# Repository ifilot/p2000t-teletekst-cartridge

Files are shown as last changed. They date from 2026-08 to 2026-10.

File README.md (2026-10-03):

# P2000T Teletekst Cartridge





<p align="center">
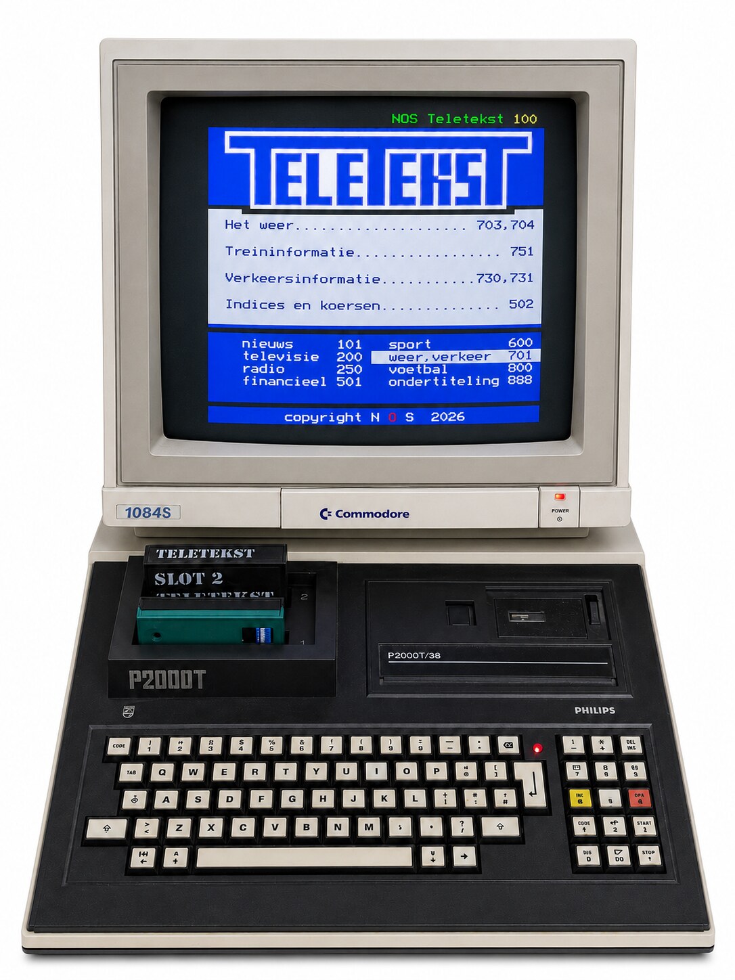
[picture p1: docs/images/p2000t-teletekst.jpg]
Philips P2000T displaying NOS Teletekst through the cartridge
  
</p>

## Introduction

The P2000T Teletekst Cartridge brings internet-connected teletext to the Philips
P2000T. A slot-1 ROM provides the native SAA5050 user interface, while a
Raspberry Pi Pico W or Pico 2 W interface in slot 2 manages Wi-Fi and fetches
pages from the NOS service, the P2000T community service,
[TeletekstArchief.nl](https://teletekstarchief.nl), or a user-supplied HTTP(S)
server. Together, they provide wireless network setup, optional
encrypted credential storage, and direct three-digit page selection on the
original computer.

This repository contains the public hardware and client side of the P2000T
Teletekst project:

- `src/` is the 16 KiB slot-1 cartridge client.
- `firmware/` is the Raspberry Pi Pico W firmware for the slot-2 interface.
- [`docs/protocol.md`](docs/protocol.md) defines the P2WP/2–8 link protocol
  between them.
- [`docs/custom-server.md`](docs/custom-server.md) gives the small HTTP/JSON
  contract needed to host your own pages.
- [`server/`](server/) contains a dependency-free Python example server and
  editable test page.
- `pcb/` contains the KiCad hardware design and manufacturing files.
- `enclosure/` contains the enclosure and label models.

## Downloads

Download the latest release artifacts:

- [P2000T cartridge ROM (`p2wp-cartridge.bin`)](https://github.com/ifilot/p2000t-teletekst-cartridge/releases/latest/download/p2wp-cartridge.bin)
- [Raspberry Pi Pico W firmware (`p2wp-pico-w.uf2`)](https://github.com/ifilot/p2000t-teletekst-cartridge/releases/latest/download/p2wp-pico-w.uf2)
- [Raspberry Pi Pico 2 W firmware (`p2wp-pico-2-w.uf2`)](https://github.com/ifilot/p2000t-teletekst-cartridge/releases/latest/download/p2wp-pico-2-w.uf2)

## Installing the firmware

Download all required binaries from the [Downloads](#downloads) section. Turn
the P2000T off before inserting or removing either cartridge.

### Slot-1 cartridge ROM

`p2wp-cartridge.bin` is a raw, signed 16 KiB ROM image for the slot-1
Teletekst cartridge. The programming procedure depends on the ROM, EEPROM, or
flash cartridge being used:

1. Select the exact memory device fitted to the cartridge in its programmer or
   flashing software.
2. Load `p2wp-cartridge.bin` as a raw binary. Do not byte-swap or add a file
   header.
3. Erase the device first if its technology requires it, then program and
   verify all 16,384 bytes.
4. Disconnect the programmer and insert the cartridge into slot 1 while the
   P2000T is powered off.

If the cartridge has an integrated loader rather than a removable memory chip,
follow that cartridge's instructions and use `p2wp-cartridge.bin` as its ROM
image. Do not guess a memory-device setting: an incorrect programming voltage
or pin configuration can damage the device.

### Pico W or Pico 2 W

> [!IMPORTANT]
> The Pico W and Pico 2 W use different firmware images, and the module marking
> may be hidden inside the cartridge. When the BOOTSEL drive opens in File
> Explorer, identify the Pico by its drive name: `RPI-RP2` means Pico W and
> `RP2350` means Pico 2 W. Do not copy a firmware file until the drive name has
> been checked.

| Installed module | BOOTSEL drive | Firmware file |
| --- | --- | --- |
| Raspberry Pi **Pico W** (RP2040) | `RPI-RP2` | `p2wp-pico-w.uf2` |
| Raspberry Pi **Pico 2 W** (RP2350) | `RP2350` | `p2wp-pico-2-w.uf2` |

1. Turn off the P2000T. Leave it off throughout the update.
2. Connect a data-capable USB cable to the Pico while holding its **BOOTSEL**
   button, then release the button when the USB drive appears.
3. In File Explorer (or the equivalent file manager), check the BOOTSEL drive
   name against the table above to determine which Pico variant is installed.
4. Copy the matching `.uf2` file to that drive. The drive automatically ejects
   and the Pico reboots when programming is complete.
5. Unplug the USB cable, install the slot-2 cartridge if it was removed, and
   then power on the P2000T.

BOOTSEL is stored in the Pico's read-only boot ROM, so this update method
remains available even if an earlier firmware image does not start. See the
official [Raspberry Pi drag-and-drop instructions](https://www.raspberrypi.com/documentation/microcontrollers/c_sdk.html#your-first-binaries)
for more detail.

#### Pico W versus Pico 2 W performance

Both modules provide the same cartridge features and should feel the same in
normal use. Page loading is dominated by the shared CYW43439 wireless subsystem,
Internet and server latency, and the same negotiated P2WP cartridge transport, so the
Pico 2 W's faster processor is not expected to provide a noticeable benefit
here.

## Hardware

<p align="center">
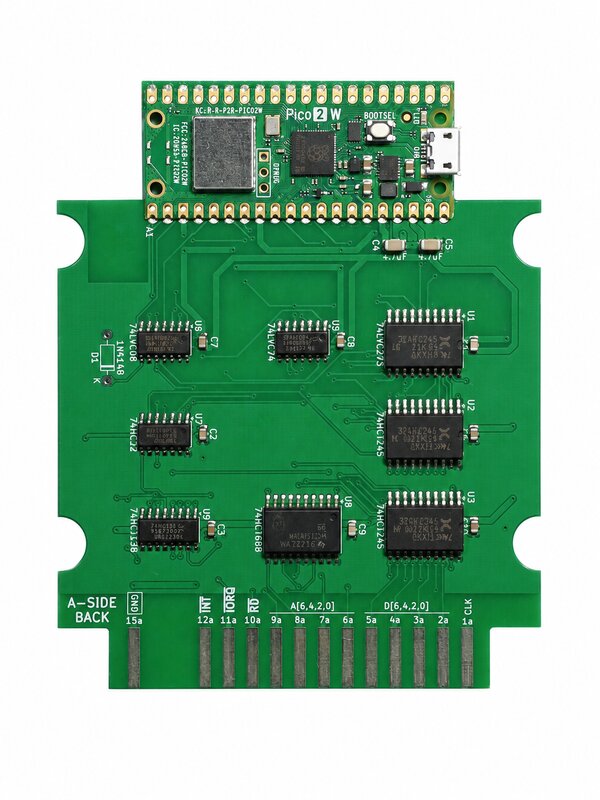
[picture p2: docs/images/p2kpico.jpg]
P2000T Teletekst cartridge with Raspberry Pi Pico 2 W
  
</p>

### Enclosure

<p align="center">
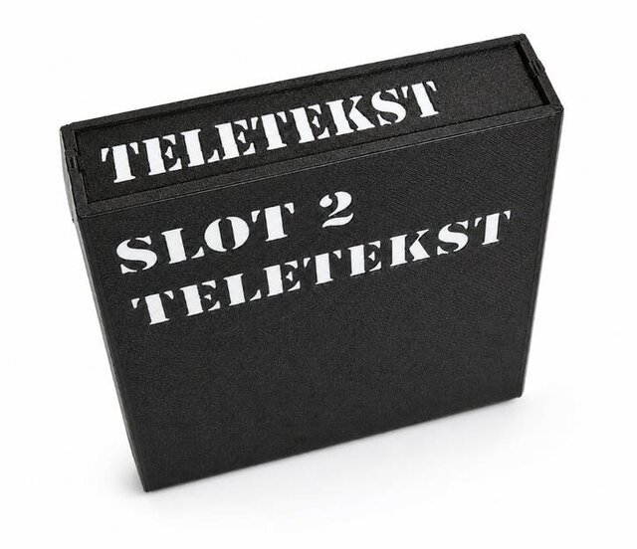
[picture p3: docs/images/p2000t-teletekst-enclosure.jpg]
Completed P2000T Teletekst cartridge enclosure
  
</p>

The printable enclosure and label models are available in [`enclosure/`](enclosure/).

### Circuit schematic

<p align="center">
  <a href="pcb/p2000t-pico-web-interface.svg">
    P2000T Teletekst cartridge circuit schematic
  </a>
</p>

## Documentation

The source menu offers NOS, P2000T Teletekst, TeletekstArchief.nl, international channels through PetsciiProxy, and a custom
server. Press `A` on that menu to choose which source should start after the
opening screen has been left untouched for 60 seconds; cycle to `UIT` to disable
auto-start. The opening prompt shows the remaining `AUTO-MODE` seconds beside
`DRUK OP EEN TOETS`. An automatic start also enables automatic next-page mode.

Choose **1 - NOS TELETEKST** for `https://teletekst-data.nos.nl`. For example,
page 101 is available at `https://teletekst-data.nos.nl/json/101-0`; the NOS
source already uses this service, so no custom server URL is needed.

Choose **4 - PETSCIIPROXY.NL** for the channels at
[`http://petsciiproxy.nl:8080`](http://petsciiproxy.nl:8080). Use `P`/`N` or the
arrow keys to browse four lists, `1`–`9` to select a channel, and `STOP` to
return. The 35 presets include ARD, ZDF, ORF, Ceefax, Teefax, Nordic and Swiss
services, and community channels. This requires updated Pico firmware supporting
P2WP/8. Channel selection lasts for the session; the saved custom URL and
autostart choice are preserved. Availability depends on the upstream service;
MTVA is omitted because upstream lists it as offline. Accented letters use
Viewdata fallbacks where the P2000T character set cannot display them.
The cartridge date/time overlay is disabled for these channels so their own
header clock remains visible. This default is configured in the cartridge ROM.

### Keymap

The on-screen help uses the P2000T's native `←` and `→` display glyphs for the
physical arrow keys. Those arrows and `P`/`N` select pages. The literal `<` and
`>` keys select the previous and next subpage; `S` selects one directly and `A`
pauses or resumes automatic rotation. `L` also toggles this subpage looping.
While paused, automatic page navigation also waits, keeping the displayed
page and subpage fixed until you resume.

| Context | Key | Action |
| --- | --- | --- |
| Page | `100`–`899` | Type three digits to fetch a page; Backspace edits an unfinished number |
| Page | `START` or `I` | Go to index page 100 |
| Page | `←` or `P`; `→` or `N` | Follow the server's previous/next-page link |
| Page | `<`; `>` | Fetch the numerically previous/advertised next subpage |
| Page | `S` | Select a subpage (`00` asks for the default subpage) |
| Page | `L` / `A` | Toggle automatic subpage looping (pause/resume) |
| Page | `V` | Toggle automatic next-page mode |
| Page | `?` or `R` | Reveal or conceal hidden text |
| Page | `Z` | Cycle normal, upper-half, and lower-half zoom |
| Page | `H` | Open the on-screen help page; any key returns |
| Page | `W` | Return to Wi-Fi setup |
| Page | `STOP` | Return to source selection |
| Source menu | `1`, `2`, `3`, `4`, or `0` | Choose NOS, P2000T, Archive, international channels, or a custom server |
| Source menu | `A` | Cycle the persistent 60-second auto-start source |
| Source menu | `H` | Open the on-screen help page |
| Input dialog | Backspace | Delete the last character or digit |
| Input dialog | Shift-`STOP` | Cancel Wi-Fi or custom-server input |

The main number row and numeric keypad both work for page and subpage entry.

Choose **0 - EIGEN SERVER** to enter an `http://` or `https://` URL of up to 96
characters, including an optional port and base path. The address is retained
in Pico flash and is filled in the next time this dialog opens. Flash is only
updated when the address changes. See [Hosting a custom Teletekst
server](docs/custom-server.md) for the required routes and response fields.

> [!WARNING]
> Certificate and hostname verification is disabled for a custom HTTPS server,
> so self-signed and private-CA certificates work. Use only a server and network
> you trust. The built-in services continue to use verified HTTPS. Archive
> requires P2WP/7 so it always uses the dedicated, verified transport.

[`docs/protocol.md`](docs/protocol.md) is the canonical P2WP/2–8 interface
specification. The Sphinx documentation also includes a
[P2000T BASIC](docs/basic.rst) client guide.

Pushes to `master` publish the rendered documentation to
[GitHub Pages](https://ifilot.github.io/p2000t-teletekst-cartridge/). Manual
deployment is also available from the GitHub Actions page. Before the first
deployment, select **GitHub Actions** as the publishing source under
**Settings → Pages**.

Build the HTML documentation with:

```sh
python3 -m pip install -r docs/requirements.txt
make -C docs html
```

## Compilation

### Quick start

From the repository root, `make run` builds the emulator and cartridge and
boots it in the emulator. This needs the dependencies listed in
[`emulator/README.md`](emulator/README.md). Append emulator options with
`ARGS`, for example `make run ARGS="--p2wp-version 2"`, or replace the network
mode with `EMUFLAGS`.

### Cartridge

Build the production C cartridge in the pinned Z88DK Docker toolchain and run
its emulator integration test with:

```sh
make -C src
make -C src smoke
```

This produces the sole release image, `build/p2wp-cartridge.bin`. See
[`src/README.md`](src/README.md) for its architecture and memory map.

### PICO Firmware

Build the firmware with `cmake -S firmware -B firmware/build -G Ninja` followed
by `cmake --build firmware/build`; this requires `PICO_SDK_PATH` to point to a
Raspberry Pi Pico SDK.

The host-side replay tool fetches a live NOS response and passes it through the
same size limit and JSON-to-SAA5050 decoder as the Pico firmware:

```sh
firmware/tools/replay-nos-page 101
firmware/tools/replay-nos-page 200-2
```

For a saved response, build with `make -C firmware/tools` and run
`firmware/tools/teletekst-replay PAGE response.json [screen.bin]`. Failures are
reported as the Pico's `06`/`07` code plus the rejected decoder stage or row,
which makes captured API responses suitable as regression fixtures.

After Wi-Fi connects, firmware can securely query the repository's latest
GitHub release. Two rows beneath the post-login source menu show that online
version beside the installed cartridge and firmware versions. Both cartridge
and Pico artifacts use the repository's canonical `VERSION` value. The Pico
generation remains available to hosts through the `DEVICE_INFO` protocol command.

The emulator directly compiles the firmware's portable production command
processor. Its end-to-end cartridge tests therefore cover the same protocol
negotiation, validation, retry/sequence rules, device information, and command
dispatch used on the Pico. Deterministic host adapters replace only GPIO,
CYW43 Wi-Fi, network timing, and flash hardware.

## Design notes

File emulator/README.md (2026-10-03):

# P2000T + Teletekst cartridge emulator

This is a focused graphical P2000T emulator for the SLOT1 ROM and SLOT2 Pico W
interface developed in this repository. It uses the M2000 Z80/P2000T core and
authentic `Default.fnt` SAA5050 glyphs. SDL provides the display and keyboard.

Dependencies: CMake, Ninja, SDL2, libcurl, and a C compiler. On Debian/Ubuntu:

```sh
sudo apt install cmake ninja-build libsdl2-dev libcurl4-openssl-dev
```

Build the cartridge and emulator:

```sh
make -C src
make -C emulator
```

and run it via

```sh
emulator/run
```

From the repository root, `make run` performs both steps and starts the
emulator with the cartridge (`build/p2wp-cartridge.bin`). Extra emulator options
go in `ARGS`, and `EMUFLAGS` replaces the default `--live` network mode:

```sh
make run ARGS="--auto-key Z"
make run EMUFLAGS="--fixture emulator/tests/fixtures/nos-100.json"
```

The emulator presents one open network named `Emulated WiFi`; select it with
`1`, decline profile storage with `N`, then choose NOS with `1`. Choose `2` for
P2000T Teletekst, `3` for TeletekstArchief.nl, `4` for the international
channel picker (P2WP/8), or `0` to type a custom server
URL. Regular host
letter, number, arrow, Enter, Backspace, Shift and keypad-Enter (P2000 STOP)
keys are mapped to the P2000T keyboard matrix. Press `F11` for a warm reset or
`F12` for a cold reset.

Page shortcuts are `START`/`I` (page 100), `?`/`R` (reveal), `Z` (top, bottom, and
normal size), arrow left/`P` and arrow right/`N` (previous/next page), `V`
(automatic next page), `<`/`>` (previous/next subpage), `A` (pause subpages),
`S` (choose subpage), `W` (Wi-Fi),
`H` (help), and P2000 `STOP` (source selection). The host
keypad Enter key maps to `STOP`; `I` is the convenient host equivalent for
`START`.

The pytest integration suite uses a tiny generated monitor shim and a recorded
NOS response, so it is deterministic and does not need proprietary ROMs or
network. Install its Python dependency once, then run it from the repository
root:

```sh
python3 -m pip install -r emulator/tests/requirements.txt
make test
```

Pytest captures the emulator's automatic-key trace on successful runs and
includes it in the failure report when a test fails.

It executes the production cartridge, completes negotiated P2WP HELLO, fictitious Wi-Fi
scan/connect, source selection, live-code JSON decoding, four chunk transfers,
and asserts that built-in and custom page content reached emulated video RAM.
It also exercises keypad entry, Backspace, arrows, Shift-STOP cancellation,
persisted auto-start, stale-label cleanup, P2WP/7 Archive gating, auto-page
error recovery, detailed P2WP/7 errors, the expanded help screen, and zoom mode.

For a deterministic custom-source boot from the repository root, run:

```sh
emulator/build/p2000t-emulator \
  --monitor /path/to/P2000ROM.bin --cartridge build/p2wp-cartridge.bin \
  --font emulator/assets/Default.fnt \
  --fixture emulator/tests/fixtures/nos-100.json \
  --headless --auto --auto-source 0 --custom-server http://terra:8080 \
  --frames 650 --dump-screen /tmp/custom-screen.bin
```

Fixture mode tests URL entry and P2WP/5 without network access. Add
`--flash /path/to/pico-flash.bin` to retain the last custom URL across emulator
runs; the file is rewritten only when the accepted URL changes. Replace the
`--fixture` pair with `--live`, change the custom URL to
`http://127.0.0.1:8080`, and run `python3 server/server.py` in another terminal
to contact the included example server. Add
`--auto-key Z`, `--auto-key RIGHT`, or `--auto-keys KP1,KP0,BACKSPACE,KP0,KP1`
to inject one or more page controls
after loading, which keeps new controls quick to test without a physical
keyboard.

The Pico side is a native simulation built around the production
`firmware/src/firmware_core.c` command processor. Consequently, negotiation,
payload validation, device/version replies, retry caching, sequence-conflict
handling, sensitive-payload erasure, and command dispatch are identical to the
real Pico firmware. The emulator supplies deterministic platform operations for
Wi-Fi, HTTP and storage; it does not simulate the RP2040/RP2350 processor,
CYW43 radio, GPIO electrical timing, or Pico SDK drivers.

Use `--p2wp-version 2` to emulate legacy firmware and exercise the cartridge's
compatibility warning, or `--p2wp-version 1` to exercise the no-common-version
error screen. Without this option the emulator negotiates the current P2WP/7.
The intermediate pre-release clock firmware can be reproduced with
`--p2wp-version 2 --p2wp-status-length 9`.

Stalled fetches reproduce the Pico firmware's 60-second HTTP timeout. Pass
`--stall-fetch` (or `--stall-fetch-after N`) to exercise it. The diagnostic
`--no-firmware-fetch-timeout` switch disables that emulation so cartridge-side
75-second fallback handling can be tested independently.

The vendored M2000 core retains its upstream copyright and is GPL-3.0; see
`LICENSE` and `vendor/m2000/UPSTREAM.md`.

For automatic international channel selection, use `--auto --auto-source 4
--auto-channel 3` (ARD). Channel indices follow the cartridge preset table,
starting at zero. Use `--live` for public PetsciiProxy access, or
`--fixture emulator/tests/fixtures/petscii-100.txt` for offline decoding.

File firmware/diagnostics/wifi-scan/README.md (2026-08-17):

# Standalone Pico W scan diagnostic

This deliberately excludes the P2000 mailbox, lwIP, and multicore code. Wi-Fi
scanning is performed directly by the CYW43 driver and does not require an IP
stack. It uses the repository's configured Pico SDK to initialize the CYW43 in
the Netherlands regulatory domain and perform one scan.

The onboard LED blinks slowly during scanning, remains on after one or more
results, and blinks rapidly after a failure or a zero-result scan. USB CDC
output reports the exact initialization and scan status every two seconds. The
diagnostic waits until a terminal has opened the USB CDC serial port before it
prints its startup messages. It then remains idle until a space character is
received over USB. CYW43 initialization and scanning only start after that
explicit command.

Build from this directory with:

```sh
cmake -S . -B build -G Ninja
cmake --build build
```

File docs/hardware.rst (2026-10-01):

Hardware design
===============

The slot-2 cartridge is a bridge between two systems with different buses and
voltage levels. On one side is the P2000T's 5 V, eight-bit I/O bus. On the
other is the Pico W's 3.3 V GPIO. The cartridge decodes three I/O addresses,
moves one byte in each direction, and provides handshake signals so that a
fast endpoint never outruns a slow one.

This page explains the circuit from functional blocks down to the individual
logic devices. The :doc:`protocol` specifies the software-visible behaviour.

At a glance
-----------

Data and handshake paths between the P2000T and Pico W

   The two byte paths are independent. ``STATUS`` lets the P2000T determine
   when it may write and when a received byte is available.

The P2000T always initiates a protocol transaction, but bytes can travel in
either direction. A one-byte input register protects Pico-bound data; the Pico
holds host-bound data stable until the P2000T reads it. Separate flip-flops
remember the state of each handshake.

Complete schematic
------------------

Complete black-and-white circuit schematic for the P2000T Pico Web Interface

   Complete cartridge circuit. Open the image separately to inspect component
   references, pin numbers, and signal names at full resolution.

The editable design is in the `KiCad schematic`_; a `standalone SVG`_ is also
available. The SVG is generated from that source in black and white.

Address decoding and port strobes
---------------------------------

The P2000T presents address bits, data bits, ``/IORQ``, ``/RD``, ``/WR``, and
``/RES`` on connector **J1**. The cartridge responds only to I/O addresses
``0x40`` through ``0x42``:

.. list-table::
   :header-rows: 1
   :widths: 16 20 24 40

   * - Port
     - Bus operation
     - Internal strobe
     - Selected circuit
   * - ``0x40``
     - Write
     - ``/WRx40``
     - U1 input register and U5A transmit-state flip-flop
   * - ``0x41``
     - Read
     - ``/RDx41``
     - U2 output-bus buffer and U5B receive-acknowledge flip-flop
   * - ``0x42``
     - Read
     - ``/RDx42``
     - U3 status-bus buffer

**U8**, a 74HCT688 equality comparator, recognizes the ``0x4x`` address
range. **U9**, a 74HCT138 decoder, then uses A0 through A2 to select ``0x40``,
``0x41``, or ``0x42``. Gates in **U7** combine those active-low selections
with the P2000T read or write control signal. This produces a strobe only for
the correct port and bus operation.

P2000T-to-Pico data path
-------------------------

#. Software waits until status bit 1, ``TX_READY``, is high.
#. An ``OUT`` to ``0x40`` places D0 through D7 on the P2000T bus and pulses
   ``/WRx40``.
#. **U1**, a 74LVC273 powered at 3.3 V, captures that byte and presents it as
   ``PD0`` through ``PD7`` to Pico GPIO0 through GPIO7.
#. The same write clocks **U5A**. Its outputs assert ``TX_FULL`` and deassert
   ``TX_READY``, recording that U1 contains an unread byte.
#. The Pico samples GPIO0 through GPIO7, then pulses ``/TX_CLR`` low. **U6A**
   combines that signal with reset and clears U5A, making ``TX_READY`` high
   again.

U1 holds the byte independently of the P2000T bus. The host must nevertheless
wait for ``TX_READY`` before every write: a second write would replace the byte
before the Pico had consumed it.

Pico-to-P2000T data path
-------------------------

#. The Pico waits for ``RX_ACK_PENDING`` to be low, then drives GPIO8 through
   GPIO15 (``PD8`` through ``PD15``) and asserts ``RX_READY``.
#. Software observes ``RX_READY`` in status bit 0 and performs an ``IN`` from
   ``0x41``.
#. ``/RDx41`` enables **U2**, a 74HCT245, which drives the Pico byte onto D0
   through D7 for the duration of the read.
#. The end of the read clocks **U5B**, asserting ``RX_ACK_PENDING`` to tell the
   Pico that the byte was accepted.
#. The Pico deasserts ``RX_READY`` and pulses ``/RX_ACK_CLR``. **U6B** then
   clears U5B so another byte can be sent.

There is no second storage register in this direction: the Pico itself keeps
GPIO8 through GPIO15 stable from ``RX_READY`` until the read is acknowledged.
Reading ``0x41`` more than once for the same byte would create an ambiguous
acknowledgement, so the host reads it exactly once.

Status register
---------------

**U3** is another 74HCT245. A read from ``0x42`` enables it and places the
following signals on the P2000T data bus:

.. list-table::
   :header-rows: 1
   :widths: 12 30 58

   * - Bit
     - Signal
     - Source or purpose
   * - 0
     - ``RX_READY``
     - Pico: a host-bound byte is stable
   * - 1
     - ``TX_READY``
     - U5A: U1 can accept another byte
   * - 2
     - ``WIFI_UP``
     - Pico application state
   * - 3
     - ``BUSY``
     - Pico application state
   * - 4
     - ``ERROR``
     - Pico application state
   * - 5
     - ``RX_ACK_PENDING``
     - U5B: the P2000T has read the current byte
   * - 6
     - ``TX_FULL``
     - U5A: U1 contains a Pico-bound byte
   * - 7
     - Ground
     - Reserved; always reads as zero

Only U2 or U3 drives the P2000T data bus, and only during its corresponding
read strobe. At all other times their outputs are high impedance. This avoids
contention with the computer and with other devices on the bus.

Voltage domains, power, and reset
---------------------------------

The cartridge receives 5 V and ground from J1. The 5 V rail powers the Pico
through ``VSYS`` and powers the 74HCT bus-side devices. The Pico's regulated
3.3 V output supplies U1, U5, and U6.

The logic families provide the level boundary. The 3.3 V 74LVC input register
accepts the P2000T's 5 V bus signals and produces 3.3 V GPIO levels. In the
opposite direction, the 5 V 74HCT245 buffers recognize the Pico's 3.3 V output
levels and drive valid 5 V-side bus levels. The control flip-flops and gates
remain in the 3.3 V domain.

**U6C** translates the active-low P2000T reset into ``/RES_3V3`` for the Pico.
Reset also clears the two handshake flip-flops, returning the transport to an
empty, known state. C1 through C3 and C6 through C10 provide local decoupling;
C4 and C5 provide bulk capacitance on the 3.3 V and 5 V rails.

Software-visible guarantees
---------------------------

The circuit deliberately provides only one byte of buffering per direction.
Software and firmware therefore form part of the transport:

* the host must poll ``TX_READY`` before writing and ``RX_READY`` before
  reading;
* the Pico must hold outgoing data stable until it sees
  ``RX_ACK_PENDING``;
* the Pico must acknowledge an incoming byte with ``/TX_CLR``;
* every wait must have a finite timeout; and
* reset discards any byte or frame that was partly transferred.

The :ref:`hardware transport section <hardware-transport>` defines the exact
handshake sequence. The :doc:`basic` guide shows how host software implements
it.

.. _KiCad schematic: https://github.com/ifilot/p2000t-teletekst-cartridge/blob/master/pcb/p2000t-pico-web-interface.kicad_sch
.. _standalone SVG: https://github.com/ifilot/p2000t-teletekst-cartridge/blob/master/pcb/p2000t-pico-web-interface.svg

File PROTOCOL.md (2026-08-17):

# P2000T to Pico W Protocol (P2WP/2)

P2WP/2 is a reliable, framed request/response protocol carried by the three
I/O ports on the P2000T Pico W interface. Multi-byte fields are little-endian.

## Hardware transport

The P2000T is the host and the Pico W is the peripheral.

| Port | P2000T operation | Name | Purpose |
| --- | --- | --- | --- |
| `0x40` | write | `HOST_TX` | Send one byte to the Pico |
| `0x41` | read | `HOST_RX` | Receive one byte from the Pico |
| `0x42` | read | `STATUS` | Read transport and application status |

The status register is defined as follows:

| Bit | Schematic signal | Meaning |
| ---: | --- | --- |
| 0 | `RX_READY` | A Pico-to-host byte is ready |
| 1 | `TX_READY` | The host may write `HOST_TX` |
| 2 | `WIFI_UP` | Informational: the network is available |
| 3 | `BUSY` | Informational: the Pico is processing a request |
| 4 | `ERROR` | Informational: the Pico detected an error |
| 5 | `RX_ACK_PENDING` | Diagnostic: the host read `HOST_RX` |
| 6 | `TX_FULL` | Diagnostic: a host-to-Pico byte is pending |
| 7 | reserved | Reads zero |

`TX_READY` and `TX_FULL` are complementary. Only `RX_READY` and `TX_READY`
are used by the P2000T transport implementation; the remaining bits are
advisory or diagnostic.

### Host to Pico byte transfer

1. The host waits until `TX_READY` is one.
2. The host writes exactly one byte to `HOST_TX`.
3. The hardware sets `TX_FULL` and clears `TX_READY`.
4. The Pico samples GPIO0 through GPIO7.
5. The Pico drives `TX_CLR` low until `TX_FULL` clears, then releases it high.

The host must never write while `TX_READY` is zero, because doing so overwrites
the byte latch.

### Pico to host byte transfer

1. The Pico waits until `RX_ACK_PENDING` is zero.
2. The Pico drives the byte on GPIO8 through GPIO15.
3. The Pico sets `RX_READY` high.
4. The host waits for `RX_READY`, then reads `HOST_RX` exactly once.
5. The hardware sets `RX_ACK_PENDING`.
6. The Pico first clears `RX_READY`, then drives `RX_ACK_CLR` low until
   `RX_ACK_PENDING` clears, and finally releases `RX_ACK_CLR` high.

Both endpoints must use a finite timeout for every wait. A transport timeout
aborts the partial frame and causes transaction recovery.

## Framing

`0x7E` is the frame delimiter. A frame consists of a delimiter, an escaped
body, and a closing delimiter. A closing delimiter may also serve as the
opening delimiter for the next frame. Repeated delimiters are idle fill.

Within the body, bytes `0x7E` and `0x7D` are encoded as `0x7D` followed by the
original byte XOR `0x20`. No other bytes are escaped.

The unescaped body is:

| Offset | Size | Field |
| ---: | ---: | --- |
| 0 | 1 | Protocol version (`0x02`) |
| 1 | 1 | Flags |
| 2 | 1 | Message type |
| 3 | 1 | Sequence number |
| 4 | 2 | Payload length |
| 6 | N | Payload |
| 6+N | 2 | CRC-16, low byte first |

The initial maximum payload is 512 bytes. Implementations may advertise a
smaller limit during `HELLO`, but must reject a frame rather than truncate it.

### Flags

| Bit | Name | Meaning |
| ---: | --- | --- |
| 0 | `RESPONSE` | Frame is a response |
| 1 | `ERROR` | Response payload starts with an error code |
| 2 | `MORE` | Additional chunks belong to this transaction |
| 3-7 | reserved | Must be sent as zero and ignored on receipt |

### CRC

The CRC covers the unescaped bytes from version through the final payload
byte. It does not cover delimiters, escape bytes, or the transmitted CRC.

P2WP/2 uses CRC-16/CCITT-FALSE:

- polynomial: `0x1021`
- initial value: `0xFFFF`
- input and output are not reflected
- final XOR: `0x0000`

A receiver silently discards malformed, oversized, truncated, or CRC-invalid
frames. It may set its local error indication and statistics counter.

## Transactions and recovery

The P2000T is the only request initiator in P2WP/2. The Pico sends a frame only
in response to a valid request. This avoids unsolicited traffic and lets future
web events be retrieved with polling requests.

- A new request uses the next sequence number modulo 256.
- A response uses the request's type and sequence number and sets `RESPONSE`.
- An empty successful response is the acknowledgement for a command with no
  result data.
- On timeout, the host retries the identical request with the identical
  sequence number. Three attempts are recommended.
- The Pico caches the most recent request identity and complete response. An
  identical retry resends that response without repeating side effects.
- Reuse of the most recent sequence number for different request content is a
  protocol error.
- After all retries fail, the host abandons the partial frame and starts again
  with `HELLO`.
- A valid non-duplicate `HELLO` starts a session and invalidates older cached
  transaction state.

An inter-byte timeout resets only the frame parser. Transaction timeouts are
message-specific; the MWE uses a short local-link timeout, while future network
operations may use longer timeouts or chunked progress responses.

## Version 2 messages

| Type | Name | Request payload | Successful response payload |
| ---: | --- | --- | --- |
| `0x01` | `HELLO` | Hello request below | Hello response below |
| `0x02` | `ECHO` | Arbitrary bytes | Identical bytes |
| `0x03` | `LINK_STATS` | Empty | Implementation counters; format reserved |
| `0x10` | `WIFI_SCAN_START` | Empty | Empty acknowledgement |
| `0x11` | `WIFI_SCAN_STATUS` | Empty | Scan state, result count, and radio state |
| `0x12` | `WIFI_SCAN_RESULT` | One-byte result index | Indexed network record |
| `0x13` | `WIFI_CONNECT` | Network index and password | Empty acknowledgement |
| `0x14` | `WIFI_STATUS` | Empty | Connection state |
| `0x20` | `WIFI_PROFILE_STATUS` | Empty | Profile state and error |
| `0x21` | `WIFI_PROFILE_CONNECT` | Empty | Empty acknowledgement |
| `0x22` | `WIFI_PROFILE_SAVE` | Wi-Fi password | Empty acknowledgement |
| `0x23` | `WIFI_PROFILE_DELETE` | Empty | Empty acknowledgement |
| `0x30` | `TELETEKST_FETCH_START` | Page, subpage, and source | Empty acknowledgement |
| `0x31` | `TELETEKST_FETCH_STATUS` | Empty | Fetch state, error, byte count, and next subpage |
| `0x32` | `TELETEKST_FETCH_ROWS` | Chunk index | Six display-ready rows |

The eight-byte `HELLO` request is:

| Offset | Field |
| ---: | --- |
| 0-3 | ASCII `P2WP` |
| 4 | Minimum supported version |
| 5 | Maximum supported version |
| 6-7 | Host maximum payload |

The eight-byte `HELLO` response is:

| Offset | Field |
| ---: | --- |
| 0-3 | ASCII `P2WP` |
| 4 | Selected version |
| 5 | Capability bits (`bit 0`: `ECHO`, `bit 1`: Wi-Fi provisioning, `bit 2`: Internet fetch, `bit 3`: encrypted Wi-Fi profile) |
| 6-7 | Negotiated maximum payload |

`HELLO` is independent of Wi-Fi state and must work while `WIFI_UP` is zero.

If the `ERROR` flag is set, the first payload byte is one of:

| Code | Meaning |
| ---: | --- |
| `0x01` | Unsupported version |
| `0x02` | Unknown message type |
| `0x03` | Invalid payload |
| `0x04` | Sequence conflict |
| `0x05` | Internal error |
| `0x06` | Wi-Fi hardware or driver unavailable |
| `0x07` | Wi-Fi operation already in progress |

## Wi-Fi provisioning

Scanning and connecting are asynchronous so the Pico can acknowledge every
link transaction quickly. The host starts an operation and polls its status;
it must not hold a P2WP transaction open for the duration of a radio scan,
authentication exchange, or DHCP request.

`WIFI_SCAN_STATUS` returns three bytes:

| Offset | Field |
| ---: | --- |
| 0 | State: `0` idle, `1` scanning, `2` complete, `3` failed |
| 1 | Number of results reported so far (final when complete) |
| 2 | Radio state: `0` initializing, `1` ready, `2` initialization failed |

Radio initialization and scanning have finite implementation deadlines. A
queued scan may report state `1` with radio state `0` while CYW43 startup is
still in progress; it changes to scan state `3` if startup or scanning exceeds
its deadline.

Results are de-duplicated by SSID, retaining the strongest access point, and
ordered by decreasing RSSI. A `WIFI_SCAN_RESULT` response is:

| Offset | Field |
| ---: | --- |
| 0 | Result index from the request |
| 1 | RSSI in dBm as a signed 8-bit integer |
| 2 | Security: `0` open, `1` supported WPA/WPA2 PSK, `2` unsupported |
| 3 | SSID length, 1-32 |
| 4 | SSID bytes, not zero-terminated |

A `WIFI_CONNECT` request contains:

| Offset | Field |
| ---: | --- |
| 0 | Index from the most recently completed scan |
| 1 | Password length, 0-63 |
| 2 | Password bytes, not zero-terminated |

The password must be empty for an open network and 8-63 bytes for a secured
network. `WIFI_STATUS` returns one state byte: `0` disconnected, `1`
connecting, `2` connected with an IP address, `3` SSID not found, `4`
authentication failed, or `5` connection failed/timed out.

## Encrypted Wi-Fi profile

The Pico may store one optional Wi-Fi profile. Profile operations are
asynchronous because authenticated decryption and flash updates can take longer
than one link transaction. The host starts an operation and polls
`WIFI_PROFILE_STATUS`, which returns:

| Offset | Field |
| ---: | --- |
| 0 | State: `0` absent, `1` encrypted profile ready, `2` operation busy |
| 1 | Last result: `0` none, `1` not found, `2` corrupt record, `3` flash failure, `4` invalid data |

`WIFI_PROFILE_CONNECT` has an empty payload. A successful asynchronous load
queues a connection using the saved SSID, password, and authentication mode.
The credentials are not returned to the host; the host continues by polling
`WIFI_STATUS`.

`WIFI_PROFILE_SAVE` is accepted only after a successful manually provisioned
connection. It contains:

| Offset | Field |
| ---: | --- |
| 0 | Wi-Fi password length, 0-63 |
| 1 | Wi-Fi password bytes |

The Pico takes the SSID and authentication mode from the current connection.
Saving replaces the previous profile. `WIFI_PROFILE_DELETE` forgets the record
by erasing its dedicated flash sector.

The reference firmware stores a fixed-length AES-256-GCM ciphertext and tag in
the final flash sector. Its key is derived from a domain-separated hash of the
Pico's unique board identifier, and every save receives a fresh random 96-bit
GCM nonce. This binds the record to one board, detects alteration, and prevents
credentials appearing as plaintext in flash. The RP2040 identifier and firmware
are not protected secrets, however, so this is not a defence against an attacker
who can dump and analyse the complete device flash.

## Teletekst fetch

Teletekst retrieval is asynchronous. Source `0` uses the public JSON endpoint
at `teletekst-data.nos.nl` over verified HTTPS; source `1` uses the compatible
P2000T Teletekst endpoint at `teletekst.philips-p2000t.nl` over verified
HTTPS. A
`TELETEKST_FETCH_START` request contains:

| Offset | Field |
| ---: | --- |
| 0-1 | Page number, little-endian (`100`-`899`) |
| 2 | Subpage (`0` selects the API's default first subpage, otherwise `1`-`99`) |
| 3 | Source: `0` NOS Teletekst, `1` P2000T Teletekst |

`TELETEKST_FETCH_STATUS` returns five bytes:

| Offset | Field |
| ---: | --- |
| 0 | State: `0` idle, `1` connecting/requesting, `2` receiving, `3` complete, `4` failed |
| 1 | Error: `0` none, `1` not connected, `2` TLS setup, `3` request start, `4` network, `5` HTTP status, `6` response too large, `7` invalid data |
| 2-3 | HTTP response bytes received so far, little-endian |
| 4 | Next subpage number, or zero when the API supplies none |

After state `3`, request chunk indexes `0` through `3` from
`TELETEKST_FETCH_ROWS`. Each successful response is exactly 240 bytes: six
consecutive 40-column rows ready to copy to the SAA5050-backed display. Together
the chunks provide the P2000T's 24 visible rows. Compatible source documents
may have 25 rows; row 25 contains Fastext prompts and is intentionally omitted.

The Pico translates HTML colour classes and Unicode private-use mosaic glyphs
into native SAA5050 bytes. Because foreground and graphics controls occupy a
visible column and take effect after that column, the encoder selects control
positions against the desired visual cells rather than inserting bytes and
shifting text. Background controls and inverse video are considered as
additional ways to reproduce the requested colours. A new successful fetch
replaces the cached screen and subpage metadata.

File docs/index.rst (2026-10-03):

P2000T Teletekst Cartridge Interface
=====================================

Welcome
-------

The P2000T Teletekst Cartridge brings internet-backed teletext to an original
Philips P2000T. The computer supplies the familiar teletext display and user
interface; a Raspberry Pi Pico W or Pico 2 W handles Wi-Fi and retrieves the
requested pages. The slot-2 cartridge connects these two very different
computers.

They communicate using **P2WP/2–8**, a small protocol designed specifically for
this interface. In simple terms, the P2000T asks the Pico to do something---for
example, connect to Wi-Fi or fetch a page---and the Pico sends a reply. P2WP
adds the checks, acknowledgements, and retry rules needed to make that exchange
reliable.

You do not need to understand every electrical signal or frame field to begin.
The BASIC guide provides a working diagnostic implementation; the protocol
specification is available when you need the exact details.

How the pieces fit together
---------------------------

.. list-table::
   :header-rows: 1
   :widths: 27 73

   * - Part
     - Role
   * - P2000T slot-1 ROM
     - Displays teletext, accepts keyboard input, and initiates every request.
   * - Slot-2 cartridge logic
     - Moves one byte at a time in either direction and exposes the three
       P2000T I/O ports.
   * - Pico W firmware
     - Responds to requests, manages Wi-Fi, and retrieves teletext pages.
   * - P2WP/2–8
     - Defines how bytes become validated requests and matching responses.

Choose a starting point
-----------------------

* **I am new to the project.** Start with the :ref:`protocol overview
  <protocol-overview>`, then use the :doc:`hardware` guide to see how the
  cartridge moves bytes between the two machines. Together they explain the
  overall system without requiring you to read every message definition.
* **I want to communicate from BASIC.** Follow the :doc:`basic` guide. It
  includes a complete ``HELLO`` and ``ECHO`` diagnostic that can be entered or
  loaded on a P2000T.
* **I am maintaining the cartridge.** See :doc:`c-size-optimization` for its
  architecture and measured ROM-size trade-offs.
* **I am implementing compatible hardware or firmware.** Use the
  :doc:`protocol` as the normative reference. Its requirements define what a
  conforming P2WP endpoint must do.
* **I want to build or download the project.** The `project README`_ links to
  release files and contains the hardware and firmware build instructions.

A transaction in plain language
-------------------------------

#. The P2000T checks that the cartridge is ready for a byte.
#. It sends a framed request, beginning a new transaction.
#. The Pico validates the request and performs the requested operation.
#. The Pico returns a response carrying the same message type and sequence
   number.
#. The P2000T validates that response. If communication times out, it can retry
   the same request safely.

``HELLO`` is always the first transaction in a session. ``ECHO`` is the best
first experiment: the Pico simply returns the bytes it received. Both client
guides demonstrate this sequence before moving on to Wi-Fi and teletext
operations.

Reference and implementation guides
-----------------------------------

.. toctree::
   :maxdepth: 2
   :caption: Interface documentation

   hardware
   protocol
   custom-server
   basic
   c-size-optimization

.. _project README: https://github.com/ifilot/p2000t-teletekst-cartridge#readme

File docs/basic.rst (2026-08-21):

P2000T BASIC client
===================

The P2000T BASIC cartridge can use P2WP/2 directly. ``INP`` reads an I/O port,
``OUT`` writes one, integer arrays can hold binary frames, and the logical
operators provide the operations required by CRC-16. The BASIC cartridge
occupies slot 1 while the Pico interface occupies slot 2.

The complete example below establishes a version-2 session and sends an
``ECHO`` request containing ``BASIC``. It implements byte handshaking, finite
timeouts, escaping, CRC generation and validation, response matching, and
three identical transaction attempts.

.. literalinclude:: examples/p2wp-basic.bas
   :language: basic
   :linenos:
   :caption: Complete P2WP/2 HELLO and ECHO diagnostic

Running the diagnostic
----------------------

#. Connect the Pico interface in slot 2 and boot the P2000T BASIC cartridge in
   slot 1.
#. Enter or load ``p2wp-basic.bas``.
#. Start the program with ``RUN``.
#. A working interface prints the selected protocol version, capability byte,
   negotiated payload limit, and ``ECHO: BASIC``.

The example advertises a 240-byte receive limit. This is the minimum usable
limit for the Internet-fetch capability because every ``TELETEKST_FETCH_ROWS``
response carries one fixed 240-byte chunk.

Program structure
-----------------

The important subroutines are:

.. list-table::
   :header-rows: 1
   :widths: 20 80

   * - Lines
     - Purpose
   * - 1000--1120
     - Construct the six-byte header and calculate the request CRC.
   * - 2000--2080
     - Update CRC-16/CCITT-FALSE while keeping separate high and low bytes.
   * - 3000--3450
     - Escape and transmit a frame through ``HOST_TX``.
   * - 4000--4650
     - Receive and unescape a frame from ``HOST_RX``.
   * - 5000--5170
     - Validate its length, CRC, version, flags, type, and sequence.
   * - 6000--6070
     - Perform a stop-and-wait transaction with identical retries.

``ER%`` is zero on success. Values 2 through 6 are local transport or frame
errors. Values 101 through 107 represent protocol errors ``0x01`` through
``0x07`` returned by the peripheral.

Do not replace the finite polling loops with BASIC's ``WAIT`` statement in a
general-purpose client. ``WAIT`` is compact, but it has no timeout and can
leave the machine blocked forever when the interface is absent or stalled.

Sending other requests
----------------------

The application sets ``TY%`` to the message type, ``PL%`` to the payload
length, stores payload bytes in ``P%()``, and calls line 6000. A successful
response body is returned in ``R%()``; its payload begins at ``R%(6)``.

For example, start a fetch of NOS page 100, using the API's default subpage:

.. code-block:: basic

   700 TY%=&H30:PL%=4
   710 PG%=100
   720 P%(0)=PG% AND 255:P%(1)=INT(PG%/256)
   730 P%(2)=0:P%(3)=0
   740 GOSUB 6000
   750 IF ER%<>0 THEN PRINT "FETCH START ERROR";ER%:STOP
   760 SQ%=(SQ%+1) AND 255

The host then polls ``TELETEKST_FETCH_STATUS`` (``TY%=&H31``, ``PL%=0``).
State 3 means that all rows are available; state 4 reports failure, with the
application error in ``R%(7)``. While state 1 or 2 is returned, delay briefly
and issue a new status transaction with the next sequence number.

After completion, request chunk indexes 0 through 3:

.. code-block:: basic

   800 FOR CK%=0 TO 3
   810 TY%=&H32:PL%=1:P%(0)=CK%:GOSUB 6000
   820 IF ER%<>0 OR R%(4)<>240 THEN PRINT "ROW ERROR":STOP
   830 FOR I%=0 TO 239
   840 RW%=CK%*6+INT(I%/40)
   850 CL%=I%-40*INT(I%/40)
   860 POKE &H5000+RW%*80+CL%,R%(6+I%)
   870 NEXT I%
   880 SQ%=(SQ%+1) AND 255
   890 NEXT CK%

The 40 display bytes in each source row are copied into the visible half of
the corresponding 80-byte P2000T video-memory row.

Recommended application sequence
--------------------------------

A full BASIC viewer should use this order:

#. Complete ``HELLO`` and check the required capability bits.
#. Query ``WIFI_PROFILE_STATUS``.
#. If a profile exists, start ``WIFI_PROFILE_CONNECT`` and poll
   ``WIFI_STATUS``.
#. Otherwise scan, retrieve the indexed results, collect a password when
   required, and start ``WIFI_CONNECT``.
#. Start a Teletekst fetch, poll its status, and retrieve all four row chunks.
#. Increment the sequence number only after every accepted response.

For a larger interactive client, a hybrid implementation is recommended:
retain menus and application logic in BASIC, but load the framing and CRC
routines into reserved RAM and call them with ``DEF USR``. This reduces page
transfer time while preserving a BASIC-facing API.

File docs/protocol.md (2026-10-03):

# P2000T to Pico W Protocol (P2WP/2–8)

P2WP is a reliable, version-negotiated request/response protocol carried by the three
I/O ports on the P2000T Pico W interface. Multi-byte fields are little-endian.

## Status and conformance

This document is the normative specification for protocol versions 2 through 8. The key
words **MUST**, **MUST NOT**, **REQUIRED**, **SHOULD**, **SHOULD NOT**, and
**MAY** describe conformance requirements.

A conforming host implementation MUST implement the hardware handshake,
framing, escaping, CRC validation, sequence matching, finite timeouts, and
`HELLO`. A conforming peripheral MUST implement the same link layer, respond to
`HELLO`, reject invalid requests with a protocol error when possible, and MUST
NOT send an unsolicited frame. Features advertised in the `HELLO` capability
byte are optional, but an endpoint MUST implement every feature that it
advertises.

The following terms are used throughout this specification:

- **Host**: the P2000T and the only endpoint permitted to initiate requests.
- **Peripheral**: the Pico W or Pico 2 W interface.
- **Body**: the unescaped header, payload, and CRC between frame delimiters.
- **Transaction**: one request and its matching response, including retries.
- **Session**: the sequence of transactions established by a valid `HELLO`.

All quantities are unsigned unless explicitly described as signed. All
multi-byte integers use little-endian byte order.

(protocol-overview)=
## Protocol overview

After either endpoint starts or resets, the host establishes a session with
`HELLO`. It then sends one request at a time and waits for the matching
response. Long-running Wi-Fi and Internet operations are started by one
transaction and observed through separate status transactions. This keeps the
local link responsive and bounds every request/response exchange.

(hardware-transport)=
## Hardware transport

The P2000T is the host and the Pico W is the peripheral.

For a circuit-level explanation of the address decoder, data buffers, and
handshake flip-flops, see {doc}`hardware`.

```{figure} images/hardware-transport.svg
:alt: Block diagram of the bidirectional byte lanes and handshake signals between the P2000T, cartridge logic, and Pico W
:width: 100%

The cartridge provides one eight-bit data lane in each direction. Handshake
signals ensure that neither endpoint overwrites an unread byte.
```

| Port | P2000T operation | Name | Purpose |
| --- | --- | --- | --- |
| `0x40` | write | `HOST_TX` | Send one byte to the Pico |
| `0x41` | read | `HOST_RX` | Receive one byte from the Pico |
| `0x42` | read | `STATUS` | Read transport and application status |

The status register is defined as follows:

| Bit | Schematic signal | Meaning |
| ---: | --- | --- |
| 0 | `RX_READY` | A Pico-to-host byte is ready |
| 1 | `TX_READY` | The host may write `HOST_TX` |
| 2 | `WIFI_UP` | Informational: the network is available |
| 3 | `BUSY` | Informational: the Pico is processing a request |
| 4 | `ERROR` | Informational: the Pico detected an error |
| 5 | `RX_ACK_PENDING` | Diagnostic: the host read `HOST_RX` |
| 6 | `TX_FULL` | Diagnostic: a host-to-Pico byte is pending |
| 7 | reserved | Reads zero |

`TX_READY` and `TX_FULL` are complementary. Only `RX_READY` and `TX_READY`
are used by the P2000T transport implementation; the remaining bits are
advisory or diagnostic.

### Host to Pico byte transfer

1. The host waits until `TX_READY` is one.
2. The host writes exactly one byte to `HOST_TX`.
3. The hardware sets `TX_FULL` and clears `TX_READY`.
4. The Pico samples GPIO0 through GPIO7.
5. The Pico drives `TX_CLR` low until `TX_FULL` clears, then releases it high.

The host MUST NOT write while `TX_READY` is zero, because doing so overwrites
the byte latch.

### Pico to host byte transfer

1. The Pico waits until `RX_ACK_PENDING` is zero.
2. The Pico drives the byte on GPIO8 through GPIO15.
3. The Pico sets `RX_READY` high.
4. The host waits for `RX_READY`, then reads `HOST_RX` exactly once.
5. The hardware sets `RX_ACK_PENDING`.
6. The Pico first clears `RX_READY`, then drives `RX_ACK_CLR` low until
   `RX_ACK_PENDING` clears, and finally releases `RX_ACK_CLR` high.

Both endpoints MUST use a finite timeout for every wait. A transport timeout
aborts the partial frame and causes transaction recovery.

## Framing

`0x7E` is the frame delimiter. A frame consists of a delimiter, an escaped
body, and a closing delimiter. A closing delimiter MAY also serve as the
opening delimiter for the next frame. Repeated delimiters are idle fill.

Within the body, bytes `0x7E` and `0x7D` are encoded as `0x7D` followed by the
original byte XOR `0x20`. No other bytes are escaped.

The unescaped body is:

| Offset | Size | Field |
| ---: | ---: | --- |
| 0 | 1 | Negotiated protocol version (`0x02` through `0x08`) |
| 1 | 1 | Flags |
| 2 | 1 | Message type |
| 3 | 1 | Sequence number |
| 4 | 2 | Payload length |
| 6 | N | Payload |
| 6+N | 2 | CRC-16, low byte first |

The protocol maximum payload is 512 bytes. Implementations MAY advertise a
smaller receive limit during `HELLO`. An endpoint MUST NOT send a payload larger
than the negotiated limit; a receiver MUST reject an oversized frame rather
than truncate it.

The Teletekst application profile uses fixed 240-byte row responses. A host
that intends to advertise or use the Internet-fetch capability MUST therefore
advertise a receive limit of at least 240 bytes.

### Flags

| Bit | Name | Meaning |
| ---: | --- | --- |
| 0 | `RESPONSE` | Frame is a response |
| 1 | `ERROR` | Response payload starts with an error code |
| 2 | `MORE` | Additional chunks belong to this transaction |
| 3-7 | reserved | Sent as zero and ignored on receipt |

A request MUST clear `RESPONSE` and `ERROR`. A successful response MUST set
`RESPONSE` and clear `ERROR`. An error response MUST set both bits and contain
at least the one-byte error code. Reserved bits MUST be sent as zero and MUST
be ignored on receipt.

### CRC

The CRC covers the unescaped bytes from version through the final payload
byte. It does not cover delimiters, escape bytes, or the transmitted CRC.

P2WP uses CRC-16/CCITT-FALSE:

- polynomial: `0x1021`
- initial value: `0xFFFF`
- input and output are not reflected
- final XOR: `0x0000`

The standard ASCII check value is `CRC("123456789") = 0x29B1`. A version-2
`HELLO` request with sequence zero and a 240-byte host limit has the following
wire representation. Its unescaped body CRC is `0xD9B2`, transmitted low byte
first. None of the body bytes require escaping in this example.

```text
7e 02 00 01 00 08 00 50 32 57 50 02 02 f0 00 b2 d9 7e
```

A receiver MUST silently discard malformed, oversized, truncated, or
CRC-invalid frames because their header cannot be trusted. It MAY set its local
error indication and statistics counter.

## Transactions and recovery

The P2000T is the only request initiator in P2WP. The Pico MUST send a frame
only in response to a valid request. This avoids unsolicited traffic and lets
future web events be retrieved with polling requests.

- The host MUST have no more than one transaction in flight.
- A new request uses the next sequence number modulo 256.
- A response MUST use the request's type and sequence number and set `RESPONSE`.
- An empty successful response is the acknowledgement for a command with no
  result data.
- On timeout, the host retries the identical request with the identical
  sequence number. Three attempts are recommended.
- The peripheral MUST cache the most recent successfully processed request
  identity and complete response. An identical retry resends that response
  without repeating side effects. Error responses for rejected requests MAY be
  sent without caching because they perform no side effects.
- Reuse of the most recent sequence number for different request content MUST
  produce `SEQUENCE_CONFLICT`.
- After all retries fail, the host abandons the partial frame and starts again
  with `HELLO`.
- A valid non-duplicate `HELLO` starts a session and invalidates older cached
  transaction state.

The host accepts a response only when its protocol version, type, sequence,
payload length, flags, and CRC are valid for the outstanding request. It MUST
discard all other frames and retry or re-establish the session. The host MUST
increment its sequence number only after accepting a complete response.

An inter-byte timeout resets only the frame parser. Transaction timeouts are
message-specific; the reference implementation uses a short local-link
timeout, while network operations MAY use longer timeouts or chunked progress
responses.

## Versioned messages

| Type | Name | Request payload | Successful response payload |
| ---: | --- | --- | --- |
| `0x01` | `HELLO` | Hello request below | Hello response below |
| `0x02` | `ECHO` | Arbitrary bytes | Identical bytes |
| `0x03` | `LINK_STATS` | Empty | Implementation counters; format reserved |
| `0x04` | `DEVICE_INFO` | Empty | Pico generation and installed firmware version |
| `0x05` | `VERSION_CHECK_START` | Empty | Empty acknowledgement |
| `0x06` | `VERSION_CHECK_STATUS` | Empty | Lookup state, error, and latest release version |
| `0x10` | `WIFI_SCAN_START` | Empty | Empty acknowledgement |
| `0x11` | `WIFI_SCAN_STATUS` | Empty | Scan state, result count, and radio state |
| `0x12` | `WIFI_SCAN_RESULT` | One-byte result index | Indexed network record |
| `0x13` | `WIFI_CONNECT` | Network index and password | Empty acknowledgement |
| `0x14` | `WIFI_STATUS` | Empty | Connection state |
| `0x20` | `WIFI_PROFILE_STATUS` | Empty | Profile state and error |
| `0x21` | `WIFI_PROFILE_CONNECT` | Empty | Empty acknowledgement |
| `0x22` | `WIFI_PROFILE_SAVE` | Wi-Fi password | Empty acknowledgement |
| `0x23` | `WIFI_PROFILE_DELETE` | Empty | Empty acknowledgement |
| `0x30` | `TELETEKST_FETCH_START` | Page, subpage, source, and optional custom URL | Empty acknowledgement |
| `0x31` | `TELETEKST_FETCH_STATUS` | Empty | Fetch state, error, byte count, navigation, and clock |
| `0x32` | `TELETEKST_FETCH_ROWS` | Chunk index | Six display-ready rows |
| `0x33` | `TELETEKST_CUSTOM_URL_LOAD` | Empty | URL length and URL bytes |
| `0x34` | `TELETEKST_CUSTOM_URL_SAVE` | URL length and URL bytes | Empty acknowledgement |
| `0x35` | `TELETEKST_SETTINGS_LOAD` | Empty | Auto-start source |
| `0x36` | `TELETEKST_SETTINGS_SAVE` | Auto-start source | Empty acknowledgement |

`LINK_STATS` reserves its message number for a future statistics format. A
host MUST NOT depend on this message until a payload format is specified. A
version-2 peripheral MAY respond with `UNKNOWN_TYPE`.

The eight-byte `HELLO` request is:

| Offset | Field |
| ---: | --- |
| 0-3 | ASCII `P2WP` |
| 4 | Minimum supported version |
| 5 | Maximum supported version |
| 6-7 | Host maximum payload |

The eight-byte `HELLO` response is:

| Offset | Field |
| ---: | --- |
| 0-3 | ASCII `P2WP` |
| 4 | Selected version |
| 5 | Capability bits (defined below) |
| 6-7 | Negotiated maximum payload |

The capability byte is defined as follows:

| Bit | Name | Meaning |
| ---: | --- | --- |
| 0 | `ECHO` | `ECHO` request support |
| 1 | `WIFI` | Wi-Fi scan, connect, and status support |
| 2 | `INTERNET` | Teletekst Internet-fetch support |
| 3 | `WIFI_PROFILE` | Encrypted Wi-Fi profile support |
| 4 | `DEVICE_INFO` | Pico generation and installed firmware query support |
| 5 | `VERSION_CHECK` | Internet-backed latest-release lookup support |
| 6-7 | reserved | Sent as zero and ignored on receipt |

The selected version MUST fall within the host's advertised range. The
negotiated maximum payload is the smaller of the host and peripheral limits and
MUST be non-zero. Reserved capability bits MUST be sent as zero and ignored on
receipt.

`HELLO` request and response frame headers use bootstrap version `2`. After a
successful response, both endpoints MUST use the selected version in every
subsequent frame header. A peripheral selects the newest revision in the
intersection of its supported range and the host's advertised range. If that
intersection is empty, it returns `UNSUPPORTED_VERSION` in a bootstrap-version
error response. Later peripherals MUST retain version 2 operation, and a
version 8 peripheral MUST retain earlier operation. This allows both a new
cartridge with old Pico firmware and an old cartridge with new Pico firmware
to remain usable.

`HELLO` is independent of Wi-Fi state and MUST work while `WIFI_UP` is zero.

### Device and release information

`DEVICE_INFO` is independent of Wi-Fi state. Its four-byte response is:

| Offset | Field |
| ---: | --- |
| 0 | Hardware (`1`: Pico W/RP2040, `2`: Pico 2 W/RP2350) |
| 1 | Installed firmware major version |
| 2 | Installed firmware minor version |
| 3 | Installed firmware patch version |

Cartridge and Pico artifacts built from one repository release carry the same
three-component version. The hardware field describes the module for which the
running firmware was compiled; zero and unrecognized values are reserved.

`VERSION_CHECK_START` starts an asynchronous HTTPS lookup of the repository's
latest GitHub release. It requires a working Internet connection and returns an
empty acknowledgement once queued. `VERSION_CHECK_STATUS` has a five-byte
response:

| Offset | Field |
| ---: | --- |
| 0 | State (`0`: idle, `1`: running, `2`: complete, `3`: failed) |
| 1 | Error (`0`: none, `1`: not connected, `2`: TLS setup, `3`: request start, `4`: network, `5`: HTTP status, `6`: invalid response) |
| 2 | Latest release major version (zero unless complete) |
| 3 | Latest release minor version (zero unless complete) |
| 4 | Latest release patch version (zero unless complete) |

The peripheral validates the GitHub TLS hostname and certificate chain, parses
the release `tag_name`, and never treats failure to check for an update as a
Teletekst fetch failure. Hosts poll while state is `running`; the peripheral
does not send an unsolicited completion frame.

If the `ERROR` flag is set, the first payload byte is one of:

| Code | Name | Meaning |
| ---: | --- | --- |
| `0x01` | `UNSUPPORTED_VERSION` | Unsupported version |
| `0x02` | `UNKNOWN_TYPE` | Unknown message type |
| `0x03` | `INVALID_PAYLOAD` | Invalid payload |
| `0x04` | `SEQUENCE_CONFLICT` | Sequence conflict |
| `0x05` | `INTERNAL` | Internal error |
| `0x06` | `WIFI_UNAVAILABLE` | Wi-Fi hardware or driver unavailable |
| `0x07` | `WIFI_BUSY` | Wi-Fi operation already in progress |

Unknown error codes MUST be treated as an unspecified transaction failure.

## Wi-Fi provisioning

Scanning and connecting are asynchronous so the Pico can acknowledge every
link transaction quickly. The host starts an operation and polls its status;
it MUST NOT hold a P2WP transaction open for the duration of a radio scan,
authentication exchange, or DHCP request.

`WIFI_SCAN_STATUS` returns three bytes:

| Offset | Field |
| ---: | --- |
| 0 | State: `0` idle, `1` scanning, `2` complete, `3` failed |
| 1 | Number of results reported so far (final when complete) |
| 2 | Radio state: `0` initializing, `1` ready, `2` initialization failed |

Radio initialization and scanning have finite implementation deadlines. A
queued scan may report state `1` with radio state `0` while CYW43 startup is
still in progress; it changes to scan state `3` if startup or scanning exceeds
its deadline.

Results are de-duplicated by SSID, retaining the strongest access point, and
ordered by decreasing RSSI. A `WIFI_SCAN_RESULT` response is:

| Offset | Field |
| ---: | --- |
| 0 | Result index from the request |
| 1 | RSSI in dBm as a signed 8-bit integer |
| 2 | Security: `0` open, `1` supported WPA/WPA2 PSK, `2` unsupported |
| 3 | SSID length, 1-32 |
| 4 | SSID bytes, not zero-terminated |

A `WIFI_CONNECT` request contains:

| Offset | Field |
| ---: | --- |
| 0 | Index from the most recently completed scan |
| 1 | Password length, 0-63 |
| 2 | Password bytes, not zero-terminated |

The password MUST be empty for an open network and 8-63 bytes for a secured
network. `WIFI_STATUS` returns one state byte: `0` disconnected, `1`
connecting, `2` connected with an IP address, `3` SSID not found, `4`
authentication failed, or `5` connection failed/timed out.

## Encrypted Wi-Fi profile

The Pico MAY store one optional Wi-Fi profile. Profile operations are
asynchronous because authenticated decryption and flash updates can take longer
than one link transaction. The host starts an operation and polls
`WIFI_PROFILE_STATUS`, which returns:

| Offset | Field |
| ---: | --- |
| 0 | State: `0` absent, `1` encrypted profile ready, `2` operation busy |
| 1 | Last result: `0` none, `1` not found, `2` corrupt record, `3` flash failure, `4` invalid data |

`WIFI_PROFILE_CONNECT` has an empty payload. A successful asynchronous load
queues a connection using the saved SSID, password, and authentication mode.
The credentials are not returned to the host; the host continues by polling
`WIFI_STATUS`.

`WIFI_PROFILE_SAVE` is accepted only after a successful manually provisioned
connection. It contains:

| Offset | Field |
| ---: | --- |
| 0 | Wi-Fi password length, 0-63 |
| 1 | Wi-Fi password bytes |

The Pico takes the SSID and authentication mode from the current connection.
Saving replaces the previous profile. `WIFI_PROFILE_DELETE` forgets the record
by erasing its dedicated flash sector.

The reference firmware stores a fixed-length AES-256-GCM ciphertext and tag in
the final flash sector. Its key is derived from a domain-separated hash of the
Pico's unique board identifier, and every save receives a fresh random 96-bit
GCM nonce. This binds the record to one board, detects alteration, and prevents
credentials appearing as plaintext in flash. The RP2040 identifier and firmware
are not protected secrets, however, so this is not a defence against an attacker
who can dump and analyse the complete device flash.

## Teletekst fetch

Teletekst retrieval is asynchronous. Source `0` uses the public JSON endpoint
at `teletekst-data.nos.nl` over verified HTTPS; source `1` uses the compatible
P2000T Teletekst endpoint at `teletekst.philips-p2000t.nl` over verified HTTPS.
Source `2`, introduced in P2WP/4, uses a custom base URL supplied by the host.
P2WP/8 adds dedicated source `4` for PetsciiProxy at
`http://petsciiproxy.nl:8080`. Its fetch-start payload has five bytes: the same
page, subpage, and source fields as built-in sources, followed by a channel
index (0–34). Requests use `/CHANNEL/PAGE-SUBPAGE`, including `-0` for the
default subpage. The preset order is defined by `petscii_channels` in the
reference firmware. Index `0xff` requests a locally generated channel catalogue;
subpage 0–3 selects the catalogue screen. No HTTP request is made for catalogues.
Other indices and catalogue subpages MUST be rejected as invalid payloads.
Fetch-status and row payloads remain unchanged from P2WP/7.

The reference cartridge exposes this source through **4 - PETSCIIPROXY.NL**
only after negotiating P2WP/8. Selection is retained for the cartridge session
and does not overwrite the saved custom-server URL or autostart setting.
Custom source `2` also recognises public PetsciiProxy URLs with channel paths.

PetsciiProxy responses contain optional newline-delimited `pn=p_PAGE-SUBPAGE`,
`pn=n_PAGE-SUBPAGE`, and `pn=nsPAGE-SUBPAGE` navigation fields, followed by
`<pre>`, exactly 1000 raw Teletext bytes, and `</pre>`. Previous/next page links
must be in 100–899; a next subpage must belong to the requested page and be in
0–99. Empty link values mean no advertised link. The final row is omitted from
the 24-row P2000T screen. Graphics-mode bytes with bit 7 set are reduced to seven-bit mosaics; extended Latin-1 alpha
characters use the existing Viewdata transliteration. Other metadata, such as
Fastext and link coordinates, is ignored. Fetch errors retain their P2WP/7
meanings.

Source `3`, introduced in P2WP/7, uses `teletekstarchief.nl` over verified
HTTPS. Its trust store includes both ISRG Root X1 and X2 because the service can
present either its RSA or ECDSA Let's Encrypt chain.

The reference peripheral applies a 60-second overall deadline to every HTTP
fetch. On expiry it aborts and releases the active connection before reporting
`TIMEOUT`, so a later fetch is not blocked behind stale network work. Hosts use
a longer fallback deadline for an unresponsive peripheral.

For NOS, P2000T, or Archive, a `TELETEKST_FETCH_START` request contains four bytes:

| Offset | Field |
| ---: | --- |
| 0-1 | Page number, little-endian (`100`-`899`) |
| 2 | Subpage (`0` selects the API's default first subpage, otherwise `1`-`99`) |
| 3 | Source: `0` NOS Teletekst, `1` P2000T Teletekst, or (P2WP/7) `3` TeletekstArchief.nl |

A P2WP/4 custom-source request has this variable-length payload:

| Offset | Field |
| ---: | --- |
| 0-1 | Page number, little-endian (`100`-`899`) |
| 2 | Subpage (`0` selects the API's default first subpage, otherwise `1`-`99`) |
| 3 | Source: `2` custom server |
| 4 | URL length (`1`-`96`) |
| 5... | URL bytes, not zero-terminated |

The URL MUST begin with `http://` or `https://`. The reference firmware accepts
a DNS name or IPv4 address, an optional port, and an optional base path; it
rejects credentials, query strings, fragments, and bracketless IPv6 addresses.
It appends `/json/PAGE` or `/json/PAGE-SUBPAGE` to that base URL. The address is
provided with every fetch; persistence is a separate P2WP/5 service.

### Persisted custom URL

P2WP/5 adds two commands for retaining the last accepted custom-server URL.
`TELETEKST_CUSTOM_URL_LOAD` has an empty request. Its response starts with a
length byte (`0` when no valid value is stored), followed by that many URL
bytes. `TELETEKST_CUSTOM_URL_SAVE` uses the same length-plus-bytes shape in its
request, requires a length of `1` through `96`, and returns an empty response.
Both commands use the same URL validation rules as a custom fetch.

The reference Pico implementation uses the penultimate flash sector; the final
sector remains reserved for the encrypted Wi-Fi profile. Before erasing or
programming, it validates and compares the existing URL record. An identical
URL is acknowledged without a flash write. The record includes a format marker,
explicit length, and checksum so incomplete or corrupt data is returned as an
empty result rather than copied into host memory.

### Persisted cartridge settings

P2WP/6 adds two commands for settings which must survive a power cycle.
`TELETEKST_SETTINGS_LOAD` has an empty request and returns one byte.
`TELETEKST_SETTINGS_SAVE` takes that same one-byte value and returns an empty
response. The auto-start source values are the cartridge menu identifiers:

| Value | Source selected after 60 seconds of opening-screen inactivity |
| ---: | --- |
| `0x00` | Custom server URL retained through P2WP/5 |
| `0x01` | NOS Teletekst |
| `0x02` | P2000T Teletekst |
| `0x03` | TeletekstArchief.nl (`https://teletekstarchief.nl`), usable after negotiating P2WP/7 |
| `0xff` | Auto-start disabled |

All other values are invalid. These menu identifiers are deliberately separate
from the `TELETEKST_FETCH_START` source field. In a P2WP/7 session the archive
entry uses dedicated source `3` and therefore requires P2WP/7. The reference
Pico stores the setting in the versioned custom-URL record in the penultimate
flash sector, preserving the URL when only the setting changes and avoiding a
flash write when the complete record is unchanged. A P2WP/5 record is accepted
and migrated when it is next updated.

The reference firmware deliberately disables certificate-chain and hostname
verification for source `2` HTTPS requests, allowing self-signed and private-CA
certificates. This exception MUST NOT weaken verification of sources `0`, `1`,
or `3`; Archive is unavailable before P2WP/7 rather than being routed through
the unverified custom transport. See
[Hosting a custom Teletekst server](custom-server.md) for the HTTP/JSON contract
and its security implications.

In P2WP/2, `TELETEKST_FETCH_STATUS` returns the original five-byte payload:

| Offset | Field |
| ---: | --- |
| 0 | State: `0` idle, `1` connecting/requesting, `2` receiving, `3` complete, `4` failed |
| 1 | Error: `0` none, `1` not connected, `2` TLS setup, `3` request start, `4` network, `5` HTTP status, `6` response too large, `7` invalid data, `8` page not found |
| 2-3 | HTTP response bytes received so far, little-endian |
| 4 | Next subpage number, or zero when the API supplies none or the sequence ended |

P2WP/3 extends that payload to thirteen bytes:

| Offset | Field |
| ---: | --- |
| 0 | State: `0` idle, `1` connecting/requesting, `2` receiving, `3` complete, `4` failed |
| 1 | Error: `0` none, `1` not connected, `2` TLS setup, `3` request start, `4` network, `5` HTTP status, `6` response too large, `7` invalid data, `8` page not found |
| 2-3 | HTTP response bytes received so far, little-endian |
| 4 | Next subpage number, or zero when the API supplies none or the sequence ended |
| 5 | Dutch local hour (`0`-`23`) from NTP |
| 6 | Dutch local minute (`0`-`59`) from NTP |
| 7 | Dutch local second (`0`-`59`) from NTP |
| 8 | Clock validity (`1` after NTP synchronization, otherwise `0`) |
| 9 | Dutch local day of month (`1`-`31`) |
| 10 | Dutch local month (`1`-`12`) |
| 11 | Dutch local year minus 2000 |
| 12 | Dutch local weekday (`0` Sunday through `6` Saturday) |

P2WP/4 extends the same payload to seventeen bytes:

| Offset | Field |
| ---: | --- |
| 0-12 | P2WP/3 fetch status and clock fields above |
| 13-14 | Previous page, little-endian, or zero when none is advertised |
| 15-16 | Next page, little-endian, or zero when none is advertised |

P2WP/7 extends the payload to twenty-one bytes and distinguishes transport
failures that earlier sessions report as generic network error `0x04`:

| Offset | Field |
| ---: | --- |
| 0-16 | P2WP/4 fetch status, clock, and navigation fields above |
| 17 | Raw lwIP `httpc_result_t` completion value, or zero when unavailable |
| 18 | Raw signed lwIP `err_t`, encoded as one byte, or zero when unavailable |
| 19-20 | HTTP response status, little-endian, or zero when unavailable |

The stable error field at offset 1 is:

| Code | Name | Meaning |
| ---: | --- | --- |
| `0x00` | `NONE` | No failure |
| `0x01` | `NOT_CONNECTED` | Wi-Fi has no usable connection |
| `0x02` | `TLS_CONFIG` | TLS context allocation or setup failed |
| `0x03` | `REQUEST_START` | The HTTP request could not be queued |
| `0x04` | `NETWORK` | Unspecified network failure (and the compatibility value in P2WP/2–6) |
| `0x05` | `HTTP_STATUS` | The server returned an unusable status or response |
| `0x06` | `TOO_LARGE` | The response exceeded the receive buffer |
| `0x07` | `INVALID_DATA` | The response body was not valid compatible JSON |
| `0x08` | `PAGE_NOT_FOUND` | The server returned HTTP 404 |
| `0x09` | `DNS` | Hostname resolution failed |
| `0x0a` | `CONNECT` | TCP or TLS connection establishment failed |
| `0x0b` | `CONNECTION_CLOSED` | The peer closed the connection prematurely |
| `0x0c` | `TIMEOUT` | The server did not respond before the deadline |
| `0x0d` | `OUT_OF_MEMORY` | The network stack could not allocate memory |
| `0x0e` | `CONTENT_LENGTH` | The received body length did not match the response framing |
| `0x0f` | `LOCAL_ABORT` | The local HTTP client aborted the request |

Codes `0x09` through `0x0f` are emitted only in P2WP/7 sessions. A peripheral
MUST map them to `NETWORK` in P2WP/2–6 sessions. Raw diagnostic fields expose
implementation values for troubleshooting and are not stable classifications;
hosts MUST base behavior on the stable error field.

The page values originate from the optional JSON strings `prevPage` and
`nextPage`. A present, non-empty value must be exactly three digits in the
range `100` through `899`. Missing or empty fields yield zero and disable that
direction's navigation shortcut.

After state `3`, request chunk indexes `0` through `3` from
`TELETEKST_FETCH_ROWS`. Each successful response is exactly 240 bytes: six
consecutive 40-column rows ready to copy to the SAA5050-backed display. Together
the chunks provide the P2000T's 24 visible rows. Compatible source documents
MAY have 25 rows; row 25 contains Fastext prompts and is intentionally omitted.

The clock and calendar fields are a P2WP/3 addition. When the clock-valid byte
is set, the cartridge places an alpha-yellow control
in column zero. NOS pages show `ww DD.mmm HH:MM:SS` in yellow in columns one
through eighteen. P2000T pages show the shorter `ww DD.mmm HH:MM` in columns
one through fifteen, with the time separator blinking every half second. Both
use Dutch two-letter weekdays and three-letter month names. The cartridge
advances the time, date, weekday, and blink using the P2000T's 20 ms monitor
clock between fetches, leaving provider text on the right untouched.

The Pico translates HTML colour classes and Unicode private-use mosaic glyphs
into native SAA5050 bytes. Because foreground and graphics controls occupy a
visible column and take effect after that column, the encoder selects control
positions against the desired visual cells rather than inserting bytes and
shifting text. Background controls and inverse video are considered as
additional ways to reproduce the requested colours. A new successful fetch
replaces the cached screen and subpage metadata.

After a host has observed a non-zero successor for a page, a later zero marks
the end of that page's subpage sequence. An active automatic loop MAY request
subpage zero at its next interval to return to the API's default first
subpage. It MUST NOT do so while the user has paused automatic rotation.

## Implementation requirements

Before an implementation is considered conforming, verify that it:

- uses only `RX_READY` and `TX_READY` for the mandatory byte handshake;
- applies a finite timeout to every byte and transaction wait;
- escapes only `0x7D` and `0x7E`, and calculates CRC over unescaped bytes;
- validates the complete frame before acting on its payload;
- permits only one outstanding host request;
- retries with byte-for-byte identical request content and sequence numbers;
- increments the sequence only after accepting a matching response;
- starts or re-establishes every session with `HELLO`;
- respects the negotiated payload limit and advertised capability bits;
- treats all Wi-Fi and Internet operations as asynchronous; and
- does not expose saved credentials through the host protocol.

## Client examples

- {doc}`custom-server` defines the HTTP endpoint consumed by custom source `2`.
- {doc}`basic` implements a portable link diagnostic in P2000T BASIC.
- The production cartridge under `src` is the reference host
  implementation.

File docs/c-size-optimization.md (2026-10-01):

<!--
SPDX-License-Identifier: GPL-3.0-only
This file is part of the P2000T Teletekst cartridge and describes measured ROM
optimization options for the Z88DK C implementation.
-->

# C cartridge size optimization

This note records measurements from the linked SDCC image rather than source
line counts. Function boundaries come from the Z88DK map and compiler listing;
raw-LZ4 measurements use high-compression mode without a stored-size prefix,
matching `lz4_z80.asm`.

## Implemented compression

- The 960-byte opening-screen base is stored as a 383-byte raw-LZ4 block. The
  blinking prompt, countdown, and shared version footer remain overlays.
- The 341-byte error-description table is stored as a raw-LZ4 block.
- The complete 960-byte help screen is stored as a 418-byte raw-LZ4 block.
  This replaces its procedural drawing function and separate string literals.
  `display_screen` is reused as the decode buffer, so it consumes no additional
  RAM. Returning from help re-renders the raw page and its current markers.

Whole-screen templates are most useful when nearly every row is static. The
source menu, URL editor, network list, and error screens contain dynamic fields;
compressing those screens would require a base template plus overlays. That is
still a reasonable future optimization if another feature exhausts the ROM,
but it adds more generated byte arrays and should be driven by a measured need.

## Whole-function compression experiment

The current BSS ends near `0x7e0e` and the stack starts at `0x9ff0`, leaving
about 8.5 KiB for carefully bounded RAM code. Compressing selected linked
function ranges produced these gross figures:

| Function | Linked bytes | Raw LZ4 bytes | Gross ROM saving |
| --- | ---: | ---: | ---: |
| `fetch_page` | 1,427 | 987 | 440 |
| `viewer_loop` | 1,278 | 1,038 | 240 |
| `choose_source` | 520 | 431 | 89 |
| `scan_networks` | 670 | 598 | 72 |
| `choose_custom_url` | 422 | 365 | 57 |
| `select_subpage` | 294 | 238 | 56 |

Copying the existing ROM bytes to an arbitrary RAM address is **not valid**.
SDCC emits absolute calls, jumps, and data addresses. A deployable RAM routine
must therefore be linked for its final RAM address before it is compressed.

A safe implementation would require this two-stage build:

1. Move a candidate into a dedicated compiler/linker section.
2. Give that section a fixed origin above BSS and emit it as a separate binary.
3. Compress that binary and include the block in the ROM link.
4. Reserve the exact RAM range and decompress it after CRT data/BSS setup but
   before the first call.
5. Keep calls between ROM and RAM linked against their final absolute addresses.
6. Check section overlap, decoded size, ROM checksum, emulator behaviour, and
   real hardware on every build.

Z88DK's assembler supports separate binaries for sections with their own
`ORG`, so the layout is technically feasible. It is not currently selected for
production: the best candidate saves at most roughly 400 bytes after loader
overhead, consumes 1.4 KiB of RAM, complicates the build, and puts the most
important fetch state machine outside immutable ROM. The existing LZ4 decoder
removes most decoder overhead, but not the relocation and build-system costs.
Revisit this only if a future feature cannot fit after static-screen
compression.

## Assembly candidates

The remaining large functions are state machines whose branches call many C
and platform helpers. Rewriting `fetch_page`, `viewer_loop`, or `scan_networks`
entirely in assembly would reduce maintainability for uncertain savings. Small,
stable primitives remain better candidates: fixed-layout formatting, byte
copies, screen transforms, CRC inner loops, and monitor/port access. The current
map contains no `sprintf`, `printf`, division, or multiplication runtime to
remove.

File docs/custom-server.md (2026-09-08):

# Hosting a custom Teletekst server

Choose **0 - EIGEN SERVER** and enter the server's complete base URL, for
example `http://terra:8080`, `http://192.168.1.20:8080`, or
`https://example.test/teletekst`. The maximum is 96 characters. HTTP and HTTPS,
DNS names, IPv4 addresses, ports, and a base path are supported. The cartridge
asks a P2WP/5 Pico to retain the last accepted address. It is restored whenever
the dialog is opened again, including after power cycling. Re-entering the same
address does not rewrite flash. With P2WP/4 firmware the address remains
available for the current cartridge session only.

For immediate testing, [`server/server.py`](../server/server.py) implements
this contract using only Python's standard library. Its page files are designed
to be edited directly; page 101 demonstrates concealed text using the `0x18`
SAA5050 control code. See `server/README.md` in the repository.

## Minimum HTTP contract

The Pico makes a `GET` request by appending one of these paths to the base URL:

- `/json/100` for the default subpage of page 100;
- `/json/100-2` for page 100, subpage 2.

Return HTTP `200` with a JSON body of no more than 16 KiB. Using
`Content-Type: application/json` is recommended, although the current client
does not inspect that header. The smallest practical response has these fields:

```json
{
  "nextSubPage": "",
  "binaryDisplay": "BASE64_OF_EXACTLY_960_BYTES"
}
```

`binaryDisplay` is the recommended format: base64-encode exactly 960 SAA5050
display bytes, arranged as 24 rows of 40 bytes. Those bytes are copied directly
to the visible screen, so they may contain the normal SAA5050 colour, graphics,
double-height, flash, conceal, and hold-graphics control codes.
Replace the uppercase placeholder above with that base64 string.

When the clock has synchronized, the cartridge replaces byte indexes `0`–`18`
of the first row with its yellow `ww DD.mmm HH:MM:SS` clock. Leave those 19
cells blank in a custom page header; columns 20–40 remain available for a title
and three-digit page number. The bundled Python pages use only the final three
cells for the page number, avoiding any overlap with the clock.

`nextSubPage` is required. Use an empty string to disable automatic rotation,
or a value such as `"100-2"`; its page number must match the requested page.
The optional `prevPage` and `nextPage` strings enable the `P` and `N` keys. Each
is either empty or a three-digit page from `100` through `899`:

```json
{
  "prevPage": "100",
  "nextPage": "102",
  "nextSubPage": "101-2",
  "binaryDisplay": "BASE64_OF_EXACTLY_960_BYTES"
}
```

As an alternative to `binaryDisplay`, a server may return the NOS-compatible
HTML-like `content` string. It must describe exactly 25 rows of 40 cells; the
25th Fastext row is accepted but not displayed. Because the binary format is
smaller to specify and preserves every SAA5050 attribute exactly, it is the
simplest target for a new server.

Return HTTP `404` for a page that does not exist. Other HTTP status codes are
shown as a server error.

## HTTPS security

Custom HTTPS endpoints deliberately skip certificate-chain and hostname
verification. This permits self-signed certificates and private certificate
authorities without provisioning CA certificates on the Pico. It also means a
custom connection is vulnerable to interception: use it only on a network and
with a server you trust. Certificate verification remains enabled for the two
built-in services.

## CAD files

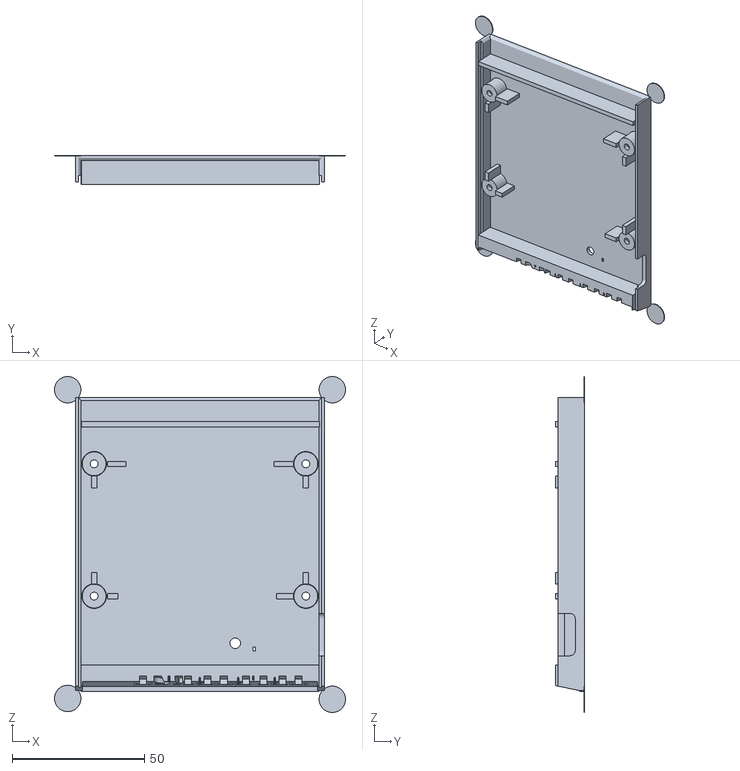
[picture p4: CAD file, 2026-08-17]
enclosure/teletekst-bottom.stl
110.0 x 11.0 x 127.0

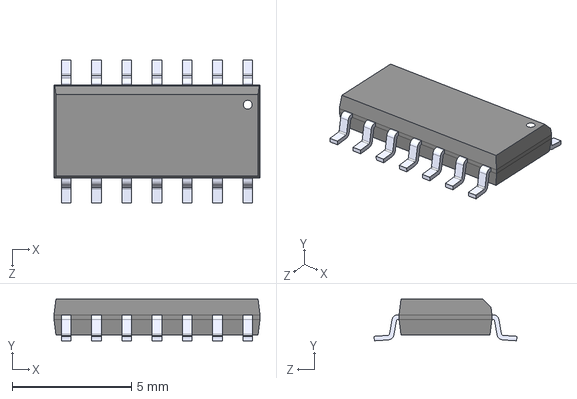
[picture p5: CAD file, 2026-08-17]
pcb/components/TXS0104ED.step
8.65 x 1.75 x 6.00 mm

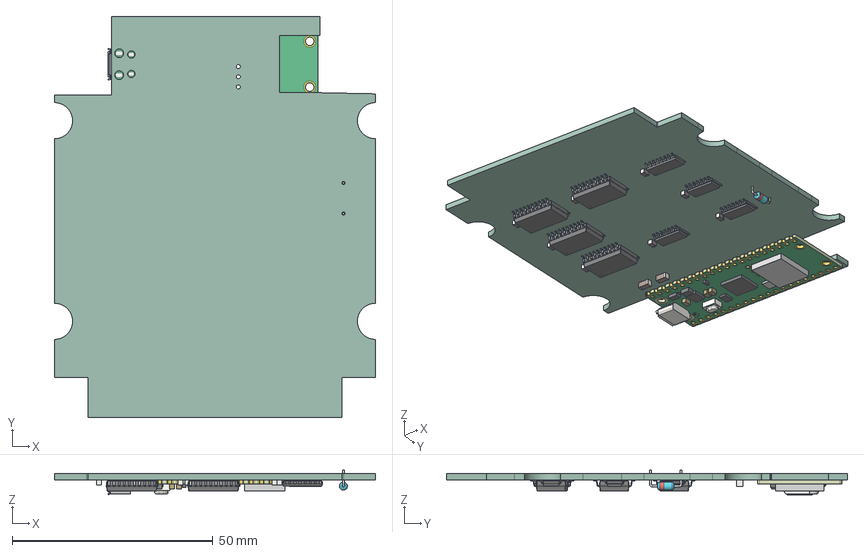
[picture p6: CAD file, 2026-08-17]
pcb/p2000t-pico.step
80.0 x 100.0 x 6.20 mm
SOIC-20W_7.5x12.8mm_P1.27mm x 4
C_1206_3216Metric x 2
RaspberryPi_Pico_W_Module_KiCad
C_0805_2012Metric x 8
SO-14_3.9x8.65mm_P1.27mm x 3
D_DO-35_SOD27_P7.62mm_Horizontal
SO-16_3.9x9.9mm_P1.27mm
p2000t-pico-web-interface_PCB

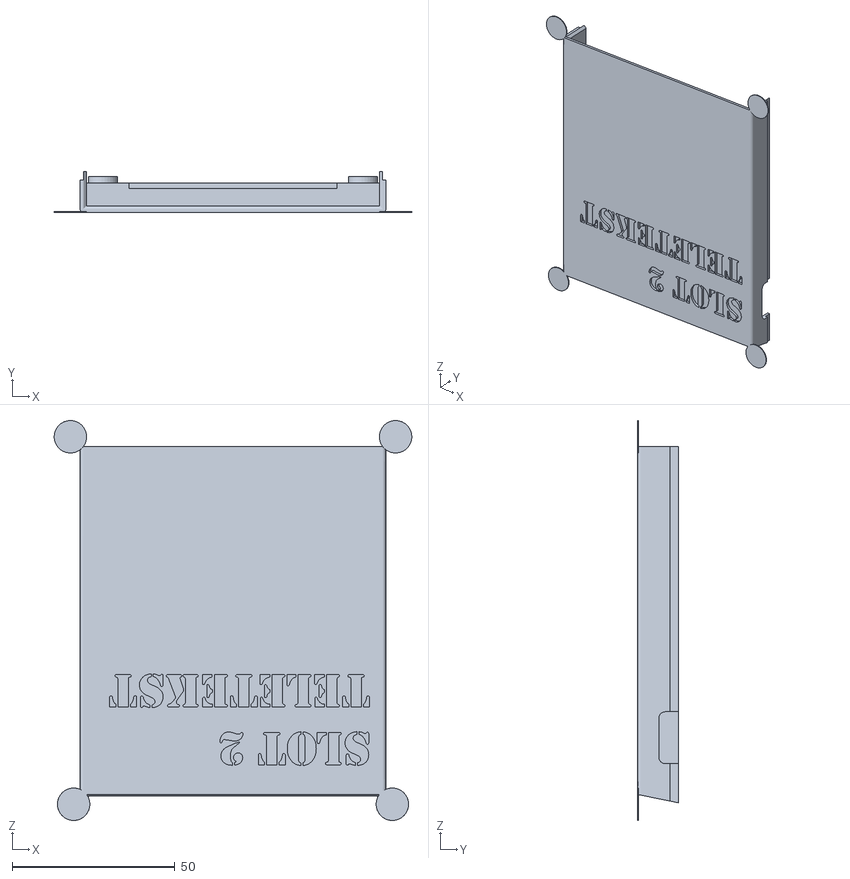
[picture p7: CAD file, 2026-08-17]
enclosure/teletekst-top.stl
110.0 x 12.5 x 123.0

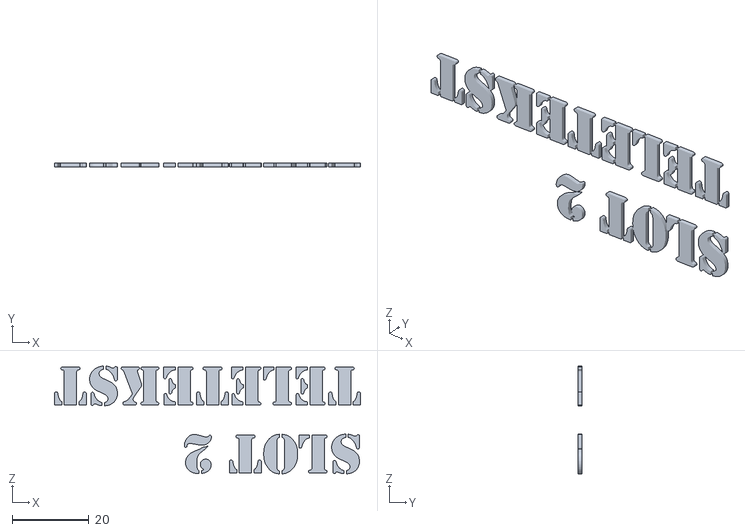
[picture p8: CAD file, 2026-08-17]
enclosure/teletekst-front-label.stl
79.9 x 1.00 x 28.2

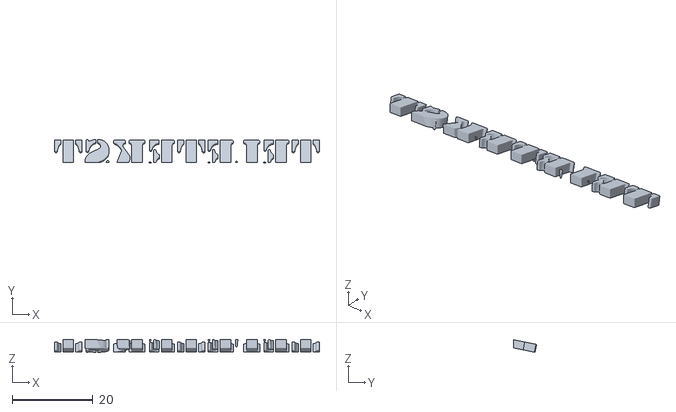
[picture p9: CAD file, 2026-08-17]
enclosure/teletekst-top-label-02.stl
65.6 x 5.77 x 3.14

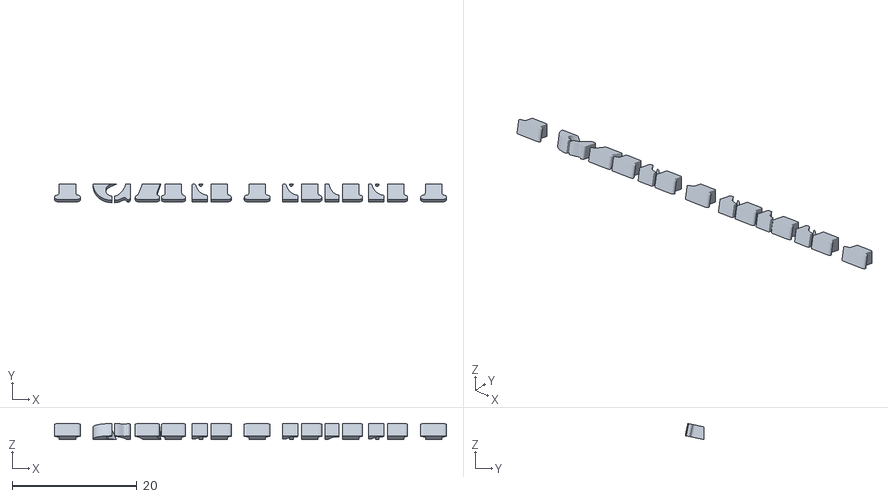
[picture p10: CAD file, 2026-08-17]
enclosure/teletekst-top-label-01.stl
62.9 x 2.98 x 2.57

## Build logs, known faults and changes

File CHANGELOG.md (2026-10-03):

# Changelog

All notable changes to the P2000T Teletekst Cartridge project are documented
in this file. The format is based on [Keep a Changelog].

Entries through version 0.2.0 were reconstructed from the tagged Git history
and release diffs.

## [Unreleased]

### Changed

- Disabled the cartridge date/time overlay for international channels by
  default, preserving provider clocks; added ROM configuration constants.

### Added

- Added **4 - INTERNATIONAAL** with a paged picker for 35 PetsciiProxy channels,
  keeping the saved custom server URL intact.
- Added P2WP/8 support for PetsciiProxy page routes, raw Teletext decoding,
  navigation metadata, and Latin-1 character fallbacks.
- Added automatic international channel selection and an offline fixture to
  the emulator, plus native decoder and cartridge integration coverage.

## [0.5.0] - 2026-08-30

### Added

- Added a second help page with compilation date/time, compiler, release
  version, and the GitHub project address, using the same coloured headings
  and blue title/footer bands as the controls page.
- Added `L` to toggle automatic subpage looping, alongside the existing `A`
  pause/resume shortcut.
- Added P2WP/7 archive transport with hostname- and certificate-verified HTTPS;
  Archive now requires P2WP/7 rather than using unverified custom transport.
- Added stable DNS, connection, closed-connection, timeout, memory,
  content-length, and local-abort fetch errors with raw HTTP/lwIP diagnostics.
- Added TeletekstArchief.nl as a predefined source.
- Added numeric-keypad page entry, Backspace correction, and left/right arrow
  aliases for previous/next page navigation.
- Added `<`/`>` previous/next subpage navigation and native P2000T arrow glyphs
  to the on-screen help page.
- Added Shift-STOP cancellation to Wi-Fi and custom-server input.
- Added a persistent P2WP/6 60-second auto-start source setting and automatic
  next-page mode, enabled automatically after a timed start, plus a visible
  opening-screen countdown.
- Added a right-aligned live clock to the missing-page screen without allowing
  it to overwrite the error header.
- Added P2WP/5 retrieval and write-minimizing Pico flash persistence for the
  last custom server URL, including file-backed emulator flash.
- Redesigned the custom-server dialog as a three-line highlighted input panel
  with clearer guidance, controls, persistence information, and footer styling.
- Added custom HTTP(S) Teletekst servers, including DNS names,
  IPv4 addresses, optional ports/base paths, and an intentionally permissive
  custom-endpoint TLS mode for self-signed and private-CA certificates.
- Added `START`/`I` index, `?`/`R` reveal, three-state `Z` zoom, and metadata-driven
  `P`/`N` previous/next page shortcuts, with an expanded on-screen reference.
- Added P2WP/4 custom URL requests and previous/next page metadata while
  retaining P2WP/2–3 compatibility.
- Added deterministic emulator coverage for custom URL entry and shortcuts.
- Added a dependency-free Python example server with editable text or raw
  SAA5050 pages and localhost HTTP tests.
- Added backward-compatible protocol commands for Pico W/Pico 2 W generation,
  installed firmware version, and an asynchronous TLS-verified GitHub latest
  release lookup.
- Added post-login source-menu rows for cartridge, Pico, and online release
  versions, plus a build/test guard that keeps cartridge and
  firmware release numbers synchronized.
- Bundled the 4096-byte P2000T monitor ROM with the emulator and made it the
  launcher's default.
- Added a portable production firmware core shared by the Pico builds and
  emulator, with native tests for negotiation, retries, sequence conflicts,
  command validation, dispatch, and sensitive-payload erasure.

### Changed

- Renamed the cartridge header to `P2K-TELETXT` to fit its 11-character field.
- Styled the Wi-Fi profile-save and fetch-error screens with shared panels,
  separators, action hints, and version footers.
- Flattened the cartridge sources into `src` and moved its generated ROM and
  build intermediates into the root `build` directory.
- Made the Z88DK C cartridge the sole production and release ROM, removing the
  legacy monolithic assembly implementation and its duplicate build/test paths.
- Moved pause/resume from `P` to `A` so `P` can mean previous page.
- Reduced the Z88DK optimizer allocation limit to shorten C-cartridge builds.
- Made the emulator reproduce the Pico firmware's 60-second stalled-fetch
  timeout while retaining an explicit cartridge-fallback test mode.

### Fixed

- Use a continuous blue background on the Wi-Fi save screen,
  and show build time in Europe/Amsterdam with automatic CET/CEST adjustment.
- Hold automatic page navigation while subpage rotation is paused, preventing
  autorun from replacing the paused page or restarting its subpage sequence.
- Redirect monitor Shift/lock status writes into hidden video columns so they
  cannot corrupt the source-menu mosaic or overwrite a live-clock digit.
- Reassert SAA5050 graphics mode at the start of the opening mosaic, restoring
  the top stroke and preventing mosaic bytes from appearing as `P` characters
  on real hardware.
- Keep a compact live clock clear of the missing-page number-entry cells in
  the C cartridge.
- Bound Teletekst HTTP work to 60 seconds in the Pico firmware, aborting the
  active connection so a timed-out request cannot block later fetches. The
  cartridge retains a 75-second fallback for an unresponsive Pico.
- Prevent graphics-mode page headers from appearing as a row of `p` characters
  while the fetch indicator is active, and label fallback error `0x81` as
  `TIMEOUT`.
- Keep the live clock updating while subpage rotation is paused, a page number
  is being entered, or either double-height zoom view is active.
- Clear the complete auto-start setting row before drawing a shorter value, so
  cycling `ARCHIEF` to `EIGEN` or `UIT` no longer leaves stale characters.
- Keep unattended auto-page mode running: content failures skip to the next
  numeric page and transport failures retry the same page. Page 100 remains a
  visible terminal health check.
- Preserve older P2WP behavior by mapping new transport errors back to generic
  network error `0x04` in P2WP/2–6 sessions.
- Wrapped an active automatic subpage loop from its final subpage back to the
  API's default first subpage, while preserving pause and resume behavior.

## [0.4.0] - 2026-08-29

### Added

- Added a visual P2000T emulator that boots the real monitor and cartridge
  ROMs and emulates the slot-2 P2WP interface, including fixture-backed and
  live Teletekst access.
- Added headless end-to-end coverage for both NOS and P2000T Teletekst sources.
- Added Dutch date and time synchronization, local clock advancement, midnight
  calendar rollover, and source-specific clock presentation.
- Added negotiated P2WP/2–3 operation, a legacy-firmware compatibility warning,
  and a dedicated no-common-protocol error screen.

### Changed

- Reworked the opening screen around a joined native SAA5050 `P2000T
  TELETEKST` mosaic logo, a blinking start prompt, and a fixed release footer.
- Polished the Teletekst source selector with aligned choices and a complete
  one-action-per-line key reference.
- Added emulator keyboard shortcuts for the P2000T STOP key and machine reset.
- Kept the original five-byte P2WP/2 fetch status for bidirectional v0.3
  compatibility; the thirteen-byte date/time status is now explicitly P2WP/3.

## [0.3.0] - 2026-08-28

### Added

- Added a two-second timeout for a missing or unresponsive Pico interface.
- Added controls for returning to Wi-Fi selection, pausing automatic subpage
  cycling, and selecting a specific subpage.
- Added a cartridge-resident Teletekst-style help page.
- Added a fully Dutch cartridge interface.
- Added a native C replay utility that runs captured or live NOS responses
  through the same Teletekst decoder used by the Pico firmware.
- Added decoder diagnostics that distinguish invalid function arguments,
  malformed external JSON fields (`nextSubPage` and `binaryDisplay`), malformed
  page content, and unrepresentable SAA5050 rows.
- Added regression coverage for bare ampersands and source rows that change
  directly between graphics and alphabetic modes.
- Added Sphinx documentation for the hardware interface, P2WP/2 assembly use,
  and P2000T BASIC use, including a complete BASIC example.
- Added GitHub Pages build and deployment jobs and a manual workflow trigger.
- Added detailed cartridge and Pico W/Pico 2 W installation instructions.

### Changed

- Added consistent Doxygen-style contracts for all maintained C functions and
  Doxygen-compatible docstrings for the cartridge signing helper.
- Removed generated `src/*.bin` cartridge images from version control; release
  workflows continue to build and publish the signed ROM.
- Cleared the previous page number when page entry starts and reserved the
  top-right cell for the pause indicator.
- Allowed the SAA5050 row compiler to use a source glyph as a control-code
  position when a page cannot otherwise be represented. Blank cells remain
  preferred, followed by graphics cells, so alphabetic text is preserved
  whenever possible.
- Moved the protocol specification into the documentation tree and expanded
  the project README and website content.

### Fixed

- Removed page numbers from error-screen headers so they cannot interfere with
  new page entry.
- Accepted bare ampersands in NOS HTML-like content instead of treating every
  ampersand as the start of an HTML entity. This fixes pages such as 101, 102,
  and 106 when their headlines contain `Saints & Stars`.
- Prevented error 07 on pages that switch directly from mosaic graphics to
  alphabetic text without reserving a cell for an SAA5050 mode control. This
  fixes pages such as 200.

## [0.2.0] - 2026-08-21

### Added

- Added support for the P2000T service's base64 `binaryDisplay` field, allowing
  exact 960-byte SAA5050 display images to preserve flash, conceal, double
  height, separated graphics, and hold graphics attributes.
- Added an exact-display regression fixture and malformed `binaryDisplay`
  validation tests.
- Added embedded Pico firmware metadata for identification with `picotool`.
- Added separate release artifacts and documentation for Pico W and Pico 2 W.
- Added the project license, release/download links, hardware imagery, and a
  rendered schematic link.

### Changed

- Revised the PCB design to hardware revision v1.1 and removed diode D1.
- Updated the enclosure bottom model for the revised hardware.
- Updated the cartridge ROM and Pico firmware release metadata to version
  0.2.0 while retaining P2WP wire-protocol version 2.

## [0.1.0] - 2026-08-17

### Added

- Initial public release of the 16 KiB P2000T slot-1 cartridge ROM.
- Initial Raspberry Pi Pico W firmware for Wi-Fi setup and Internet-backed
  Teletekst page retrieval.
- P2WP/2 framed link protocol between the P2000T cartridge and Pico interface.
- NOS and P2000T community Teletekst source selection, subpage rotation, and
  SAA5050 display compilation.
- Encrypted Wi-Fi profile storage and automatic reconnection.
- KiCad PCB design, manufacturing outputs, enclosure models, and build/release
  automation.

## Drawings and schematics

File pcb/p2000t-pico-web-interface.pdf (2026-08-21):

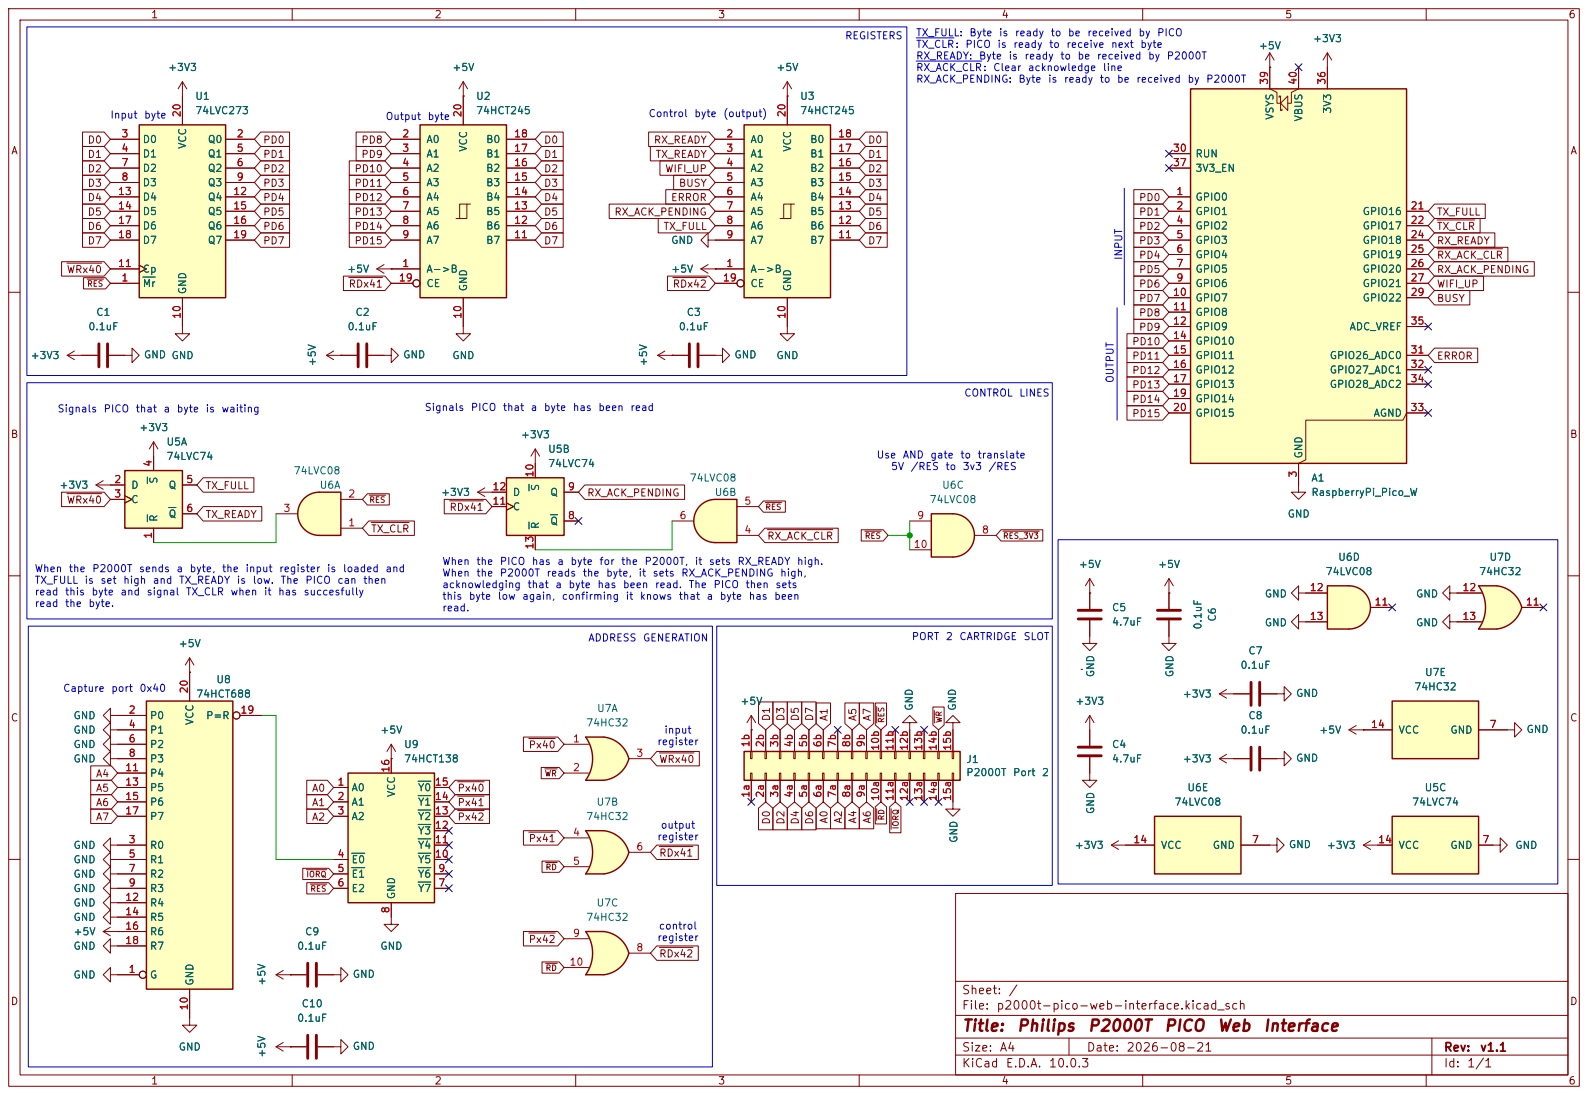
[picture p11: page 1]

TX_FULL: Byte is ready to be received by PICO

Signals PICO that a byte has been read When the PICO has a byte for the P2000T, it sets RX_READY high. When the P2000T reads the byte, it sets RX_ACK_PENDING high,

control register When the P2000T sends a byte, the input register is loaded and
TX_FULL is set high and TX_READY is low. The PICO can then
read this byte and signal TX_CLR when it has succesfully
read the byte.

acknowledging that a byte has been read. The PICO then sets
this byte low again, confirming it knows that a byte has been

Sheet: /
File: p2000t-pico-web-interface.kicad_sch
Title: Philips P2000T PICO Web Interface

Size: A4 | Rev: v1.1
KiCad E.D.A. 10.0.3 | Id: 1/1

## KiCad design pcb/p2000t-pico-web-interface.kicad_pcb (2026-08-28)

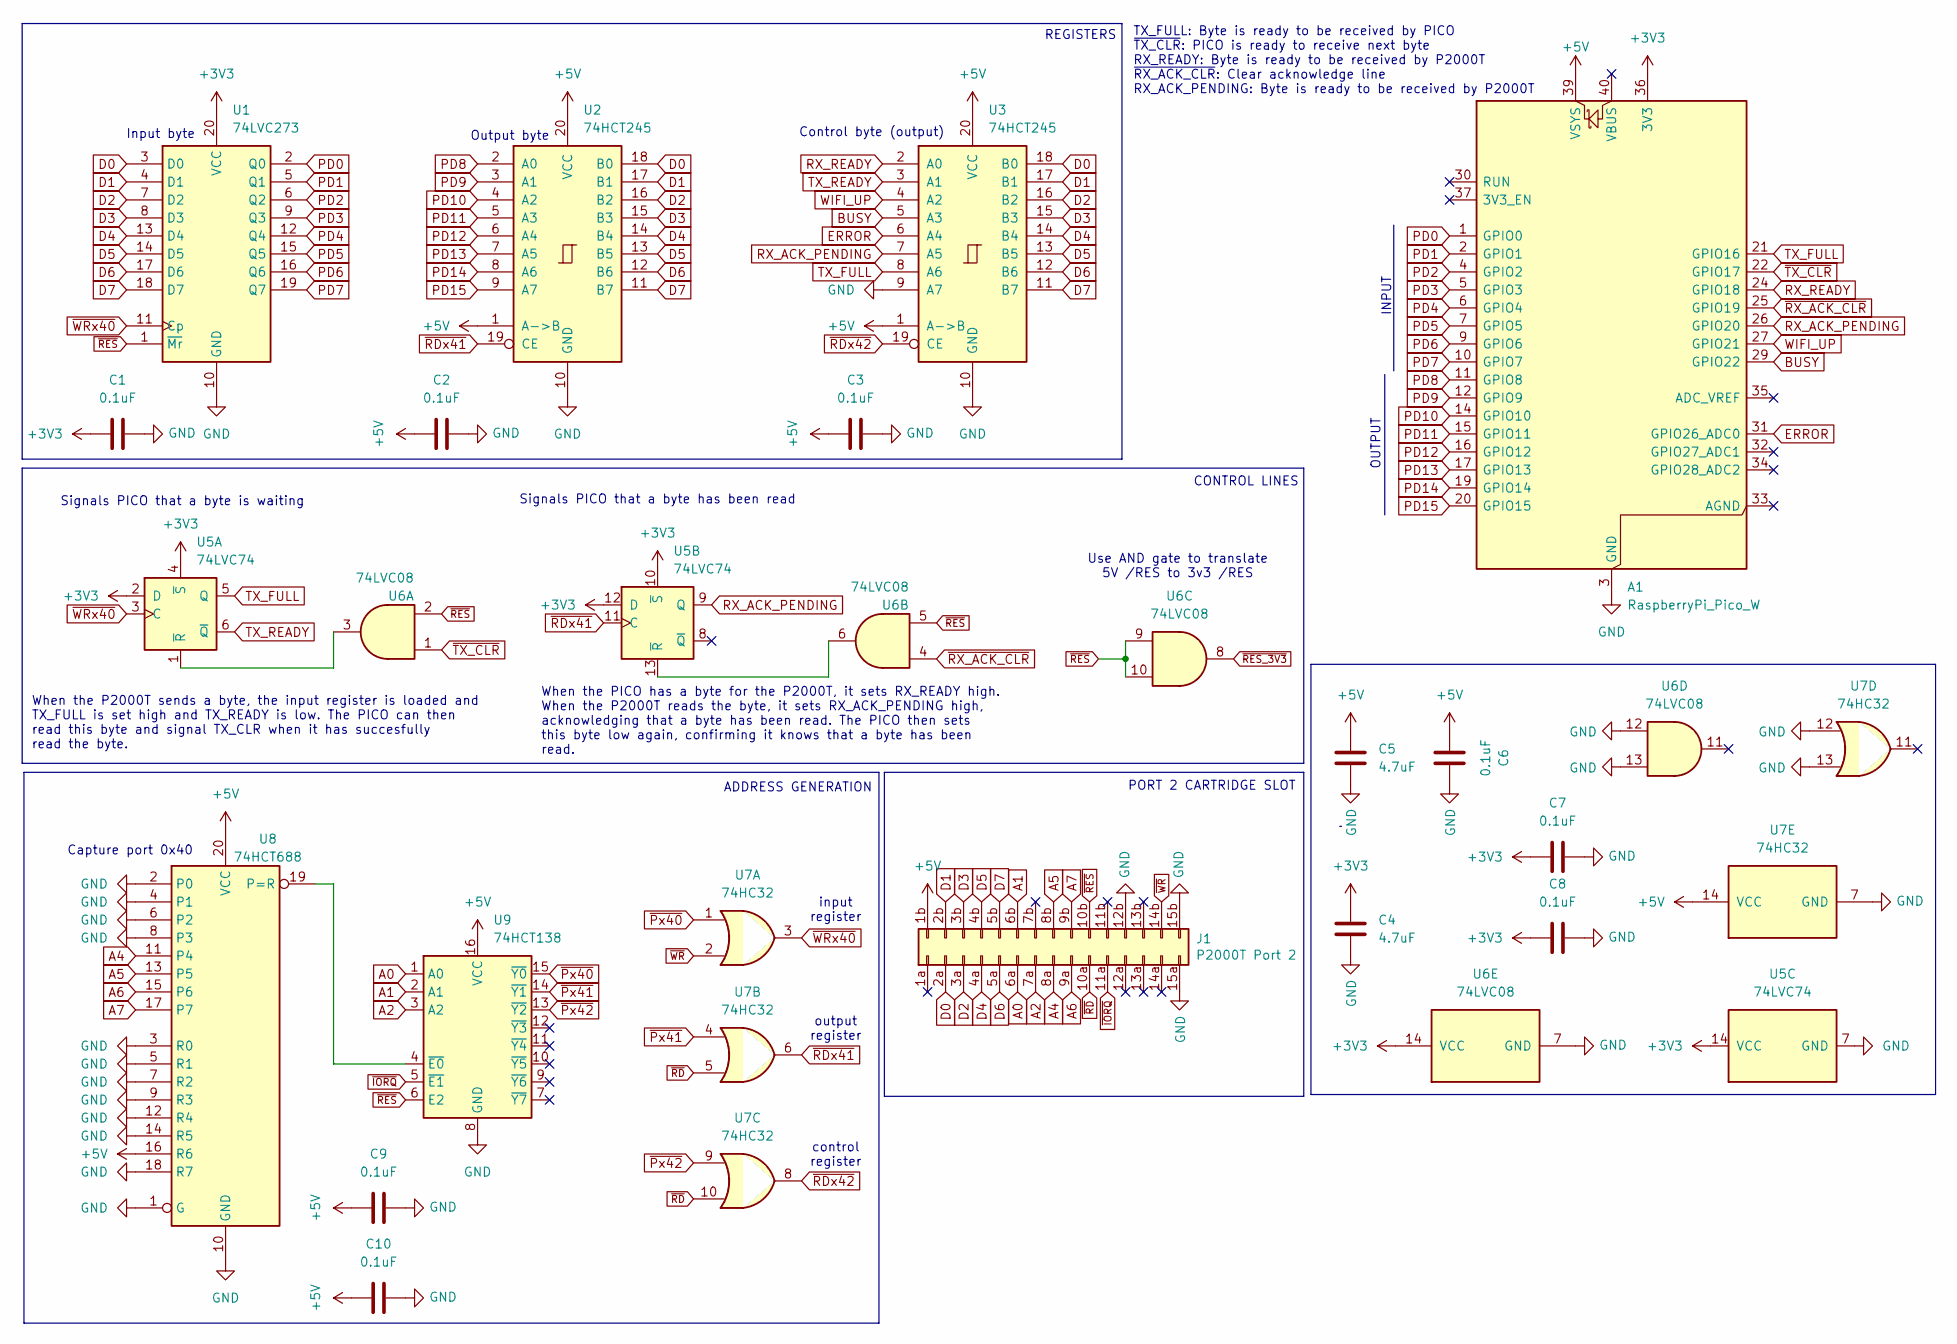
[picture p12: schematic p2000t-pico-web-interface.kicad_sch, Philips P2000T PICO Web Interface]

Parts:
A1: RaspberryPi_Pico_W; RaspberryPi_Pico_W_SMD_HandSolder
C1, C2, C3, C6, C7, C8, C9, C10: 0.1uF; C_0805_2012Metric
C4, C5: 4.7uF; C_1206_3216Metric
J1: P2000T Port 2; p2000t_cartridge_edge
U1: 74LVC273; SOIC-20W_7.5x12.8mm_P1.27mm
U2, U3: 74HCT245; SOIC-20W_7.5x12.8mm_P1.27mm
U5: 74LVC74; SO-14_3.9x8.65mm_P1.27mm
U6: 74LVC08; SO-14_3.9x8.65mm_P1.27mm
U7: 74HC32; SO-14_3.9x8.65mm_P1.27mm
U8: 74HCT688; SOIC-20W_7.5x12.8mm_P1.27mm
U9: 74HCT138; SO-16_3.9x9.9mm_P1.27mm

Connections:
+3V3: A1.36 (3V3), C1.1, C4.1, C7.1, C8.1, U1.20 (VCC), U5.2 (D), U5.4 (~S), U5.10 (~S), U5.12 (D), U5.14 (VCC), U6.14 (VCC)
+5V: A1.39 (VSYS), C2.1, C3.1, C5.1, C6.1, C9.1, C10.1, J1.1b, U2.1 (A->B), U2.20 (VCC), U3.1 (A->B), U3.20 (VCC), U7.14 (VCC), U8.16 (R6), U8.20 (VCC), U9.16 (VCC)
A0: J1.6a, U9.1 (A0)
A1: J1.6b, U9.2 (A1)
A2: J1.7a, U9.3 (A2)
A4: J1.8a, U8.11 (P4)
A5: J1.8b, U8.13 (P5)
A6: J1.9a, U8.15 (P6)
A7: J1.9b, U8.17 (P7)
BUSY: A1.29 (GPIO22), U3.5 (A3)
D0: J1.2a, U1.3 (D0), U2.18 (B0), U3.18 (B0)
D1: J1.2b, U1.4 (D1), U2.17 (B1), U3.17 (B1)
D2: J1.3a, U1.7 (D2), U2.16 (B2), U3.16 (B2)
D3: J1.3b, U1.8 (D3), U2.15 (B3), U3.15 (B3)
D4: J1.4a, U1.13 (D4), U2.14 (B4), U3.14 (B4)
D5: J1.4b, U1.14 (D5), U2.13 (B5), U3.13 (B5)
D6: J1.5a, U1.17 (D6), U2.12 (B6), U3.12 (B6)
D7: J1.5b, U1.18 (D7), U2.11 (B7), U3.11 (B7)
ERROR: A1.31 (GPIO26_ADC0), U3.6 (A4)
GND: A1.3 (GND), A1.8 (GND), A1.13 (GND), A1.18 (GND), A1.23 (GND), A1.28 (GND), A1.38 (GND), C1.2, C2.2, C3.2, C4.2, C5.2, C6.2, C7.2, C8.2, C9.2, C10.2, J1.12b, J1.15a, J1.15b, U1.10 (GND), U2.10 (GND), U3.9 (A7), U3.10 (GND), U5.7 (GND), U6.7 (GND), U6.12, U6.13, U7.7 (GND), U7.12, U7.13, U8.1 (G), U8.2 (P0), U8.3 (R0), U8.4 (P1), U8.5 (R1), U8.6 (P2), U8.7 (R2), U8.8 (P3), U8.9 (R3), U8.10 (GND), U8.12 (R4), U8.14 (R5), U8.18 (R7), U9.8 (GND)
unnamed: U5.1 (~R), U6.3
unnamed: U5.13 (~R), U6.6
unnamed: U8.19 (P=R), U9.4 (~E0)
PD0: A1.1 (GPIO0), U1.2 (Q0)
PD1: A1.2 (GPIO1), U1.5 (Q1)
PD2: A1.4 (GPIO2), U1.6 (Q2)
PD3: A1.5 (GPIO3), U1.9 (Q3)
PD4: A1.6 (GPIO4), U1.12 (Q4)
PD5: A1.7 (GPIO5), U1.15 (Q5)
PD6: A1.9 (GPIO6), U1.16 (Q6)
PD7: A1.10 (GPIO7), U1.19 (Q7)
PD8: A1.11 (GPIO8), U2.2 (A0)
PD9: A1.12 (GPIO9), U2.3 (A1)
PD10: A1.14 (GPIO10), U2.4 (A2)
PD11: A1.15 (GPIO11), U2.5 (A3)
PD12: A1.16 (GPIO12), U2.6 (A4)
PD13: A1.17 (GPIO13), U2.7 (A5)
PD14: A1.19 (GPIO14), U2.8 (A6)
PD15: A1.20 (GPIO15), U2.9 (A7)
RX_ACK_PENDING: A1.26 (GPIO20), U3.7 (A5), U5.9 (Q)
RX_READY: A1.24 (GPIO18), U3.2 (A0)
TX_FULL: A1.21 (GPIO16), U3.8 (A6), U5.5 (Q)
TX_READY: U3.3 (A1), U5.6 (~Q)
WIFI_UP: A1.27 (GPIO21), U3.4 (A2)
~IORQ: J1.11a, U9.5 (~E1)
~Px40: U7.1, U9.15 (~Y0)
~Px41: U7.4, U9.14 (~Y1)
~Px42: U7.9, U9.13 (~Y2)
~RDx41: U2.19 (CE), U5.11 (C), U7.6
~RDx42: U3.19 (CE), U7.8
~RD: J1.10a, U7.5, U7.10
~RES_3V3: U6.8
~RES: J1.10b, U1.1 (~Mr), U6.2, U6.5, U6.9, U6.10, U9.6 (E2)
~RX_ACK_CLR: A1.25 (GPIO19), U6.4
~TX_CLR: A1.22 (GPIO17), U6.1
~WRx40: U1.11 (Cp), U5.3 (C), U7.3
~WR: J1.14b, U7.2

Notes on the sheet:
input register
Capture port 0x40
TX_FULL: Byte is ready to be received by PICO ~{TX_CLR}: PICO is ready to receive next byte RX_READY: Byte is ready to be received by P2000T ~{RX_ACK_CLR}: Clear acknowledge line RX_ACK_PENDING: Byte is ready to be received by P2000T
output register
When the P2000T sends a byte, the input register is loaded and TX_FULL is set high and TX_READY is low. The PICO can then read this byte and signal TX_CLR when it has succesfully read the byte.
OUTPUT
CONTROL LINES
When the PICO has a byte for the P2000T, it sets RX_READY high. When the P2000T reads the byte, it sets RX_ACK_PENDING high, acknowledging that a byte has been read. The PICO then sets this byte low again, confirming it knows that a byte has been read.
control register
Signals PICO that a byte has been read
Input byte
Use AND gate to translate 5V /RES to 3v3 /RES
ADDRESS GENERATION
Output byte
REGISTERS
PORT 2 CARTRIDGE SLOT
Signals PICO that a byte is waiting
INPUT
Control byte (output)

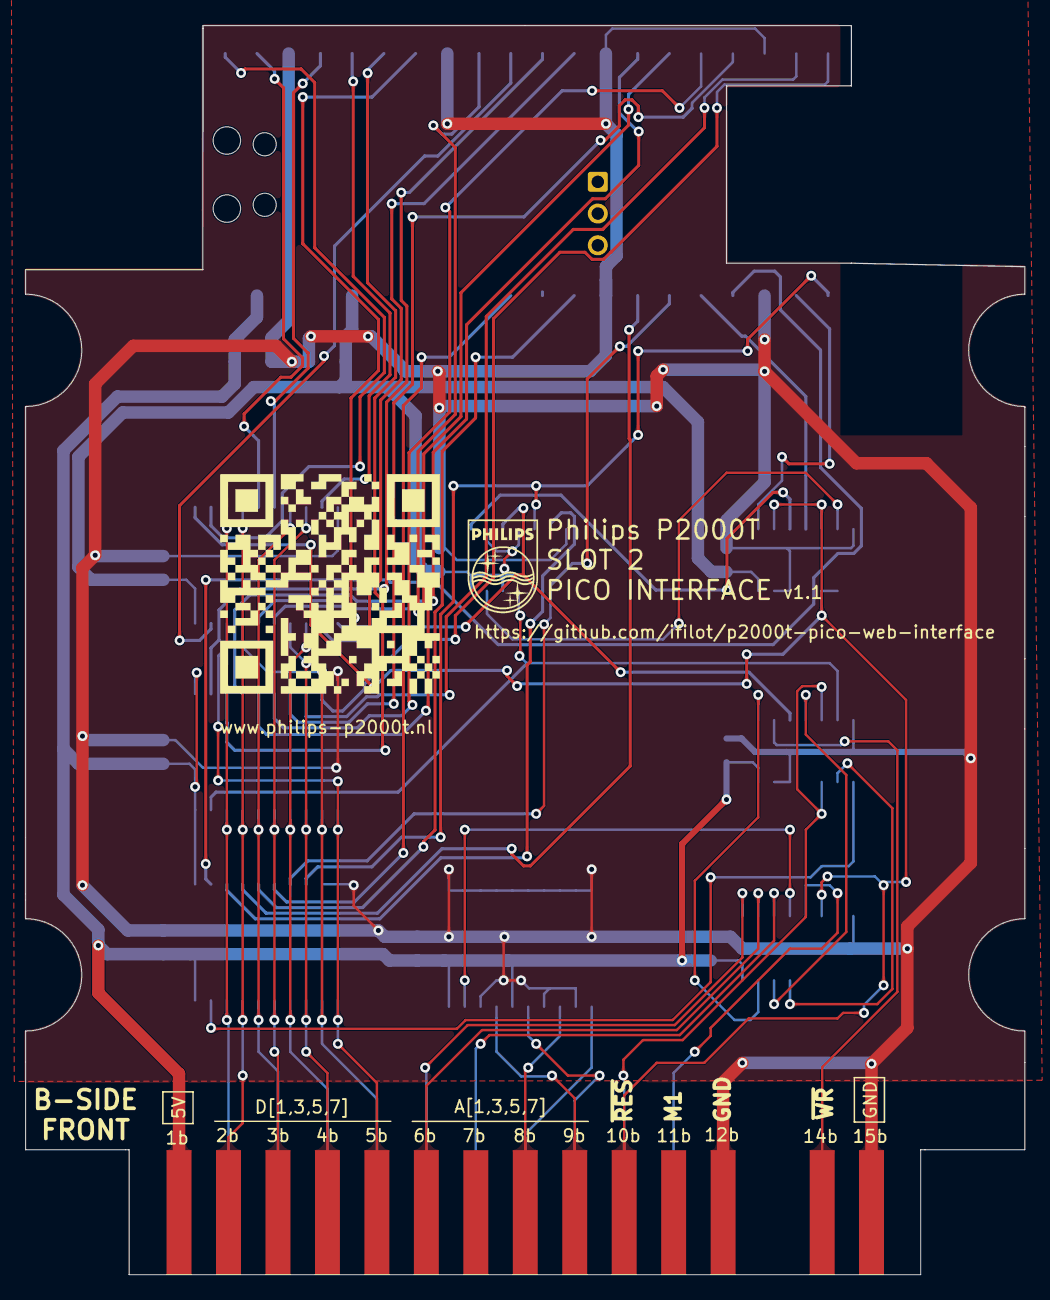
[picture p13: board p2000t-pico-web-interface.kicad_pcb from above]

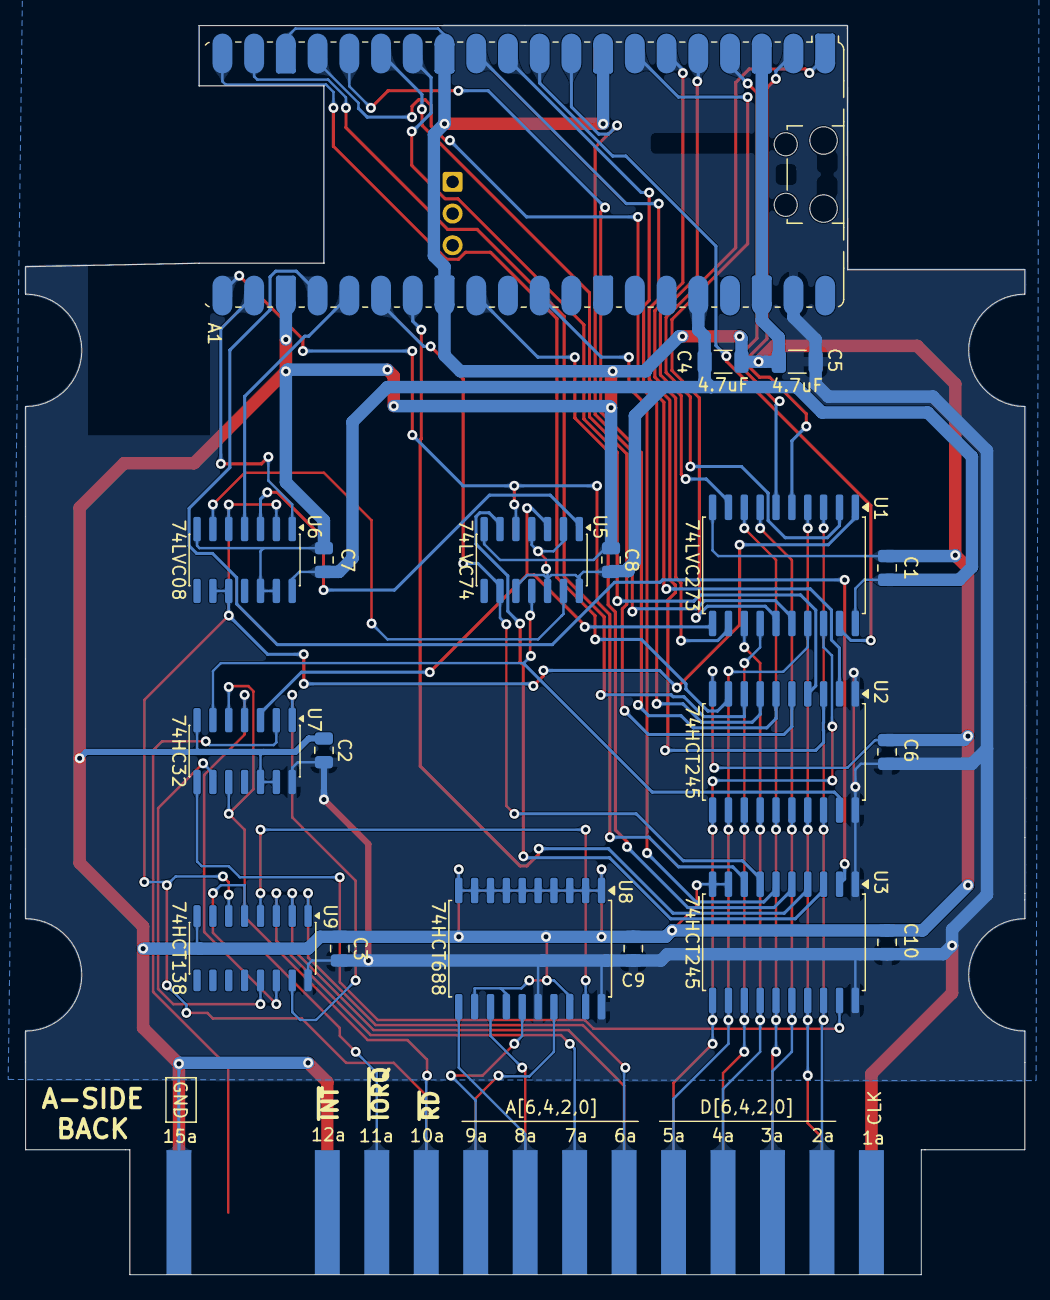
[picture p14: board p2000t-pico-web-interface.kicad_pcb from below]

Board: 2 copper layers, 80.0 x 100.0 mm, 22 parts (20 on the bottom side), 56 nets.

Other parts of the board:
G002: LOGO; qrcode
G003: LOGO; philips_logo

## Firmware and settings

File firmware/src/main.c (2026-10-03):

#include "p2wp.h"
#include "firmware_core.h"
#include "version.h"
#include "teletekst.h"
#include "custom_endpoint.h"
#include "custom_url_store.h"
#include "wifi_profile.h"
#include "github_ca.h"
#include "nos_teletekst_ca.h"
#include "p2000t_teletekst_ca.h"
#include "archive_teletekst_ca.h"

#include <stdio.h>
#include <string.h>

#include "hardware/gpio.h"
#include "lwip/altcp_tcp.h"
#include "lwip/altcp_tls.h"
#include "lwip/apps/http_client.h"
#include "lwip/dns.h"
#include "lwip/udp.h"
#include "mbedtls/ssl.h"
#include "mbedtls/platform_util.h"
#include "pico/cyw43_arch.h"
#include "pico/flash.h"
#include "pico/multicore.h"
#include "pico/stdlib.h"
#include "pico/sync.h"
#include "pico/time.h"

enum {
    GPIO_HOST_DATA_BASE = 0,
    GPIO_PICO_DATA_BASE = 8,
    GPIO_TX_FULL = 16,
    GPIO_TX_CLEAR_N = 17,
    GPIO_RX_READY = 18,
    GPIO_RX_ACK_CLEAR_N = 19,
    GPIO_RX_ACK_PENDING = 20,
    GPIO_WIFI_UP = 21,
    GPIO_BUSY = 22,
    GPIO_ERROR = 26,
};

#define HOST_DATA_MASK 0x000000ffu
#define PICO_DATA_MASK 0x0000ff00u
#define BYTE_TIMEOUT_MS 1000u
#define PARTIAL_FRAME_TIMEOUT_MS 1000u
#define WIFI_DEADLINE_CHECK_MS 10u
#define WIFI_INIT_TIMEOUT_MS 15000u
#define WIFI_SCAN_TIMEOUT_MS 15000u
#define WIFI_SCAN_QUEUE_TIMEOUT_MS \
    (WIFI_INIT_TIMEOUT_MS + WIFI_SCAN_TIMEOUT_MS)
#define WIFI_CONNECT_TIMEOUT_MS 30000u
#define WIFI_FAILURE_CONFIRM_MS 2000u
#define WIFI_MAX_RESULTS 9u
#define WIFI_MAX_PASSWORD 63u
#define TELETEKST_NOS_HOST "teletekst-data.nos.nl"
#define TELETEKST_P2000T_HOST "teletekst.philips-p2000t.nl"
#define TELETEKST_ARCHIVE_HOST "teletekstarchief.nl"
#define TELETEKST_NOS_PORT 443u
#define TELETEKST_P2000T_PORT 443u
#define TELETEKST_ARCHIVE_PORT 443u
#define TELETEKST_FETCH_TIMEOUT_MS 60000u
#define TELETEKST_ROWS_PER_CHUNK 6u
#define TELETEKST_CHUNK_SIZE \
    (TELETEKST_COLUMNS * TELETEKST_ROWS_PER_CHUNK)
#define TELETEKST_CHUNK_COUNT \
    (TELETEKST_DISPLAY_ROWS / TELETEKST_ROWS_PER_CHUNK)
#define NTP_HOST "time.cloudflare.com"
#define NTP_PORT 123u
#define NTP_PACKET_SIZE 48u
#define NTP_UNIX_EPOCH_OFFSET 2208988800u
#define NTP_RETRY_MS 30000u
#define NTP_RESYNC_MS (6u * 60u * 60u * 1000u)
#define VERSION_HOST "api.github.com"
#define VERSION_PORT 443u
#define VERSION_PATH "/repos/ifilot/p2000t-teletekst-cartridge/releases/latest"
#define VERSION_HTTP_BODY_MAX 16384u

enum wifi_scan_state {
    WIFI_SCAN_IDLE = 0,
    WIFI_SCAN_RUNNING = 1,
    WIFI_SCAN_COMPLETE = 2,
    WIFI_SCAN_FAILED = 3,
};

enum wifi_init_state {
    WIFI_INIT_STARTING = 0,
    WIFI_INIT_READY = 1,
    WIFI_INIT_FAILED = 2,
};

enum wifi_connection_state {
    WIFI_DISCONNECTED = 0,
    WIFI_CONNECTING = 1,
    WIFI_CONNECTED = 2,
    WIFI_NO_NETWORK = 3,
    WIFI_BAD_AUTH = 4,
    WIFI_CONNECTION_FAILED = 5,
};

enum wifi_security {
    WIFI_SECURITY_OPEN = 0,
    WIFI_SECURITY_PSK = 1,
    WIFI_SECURITY_UNSUPPORTED = 2,
};

enum teletekst_fetch_state {
    TELETEKST_FETCH_IDLE = 0,
    TELETEKST_FETCH_CONNECTING = 1,
    TELETEKST_FETCH_RECEIVING = 2,
    TELETEKST_FETCH_COMPLETE = 3,
    TELETEKST_FETCH_FAILED = 4,
};

enum teletekst_error {
    TELETEKST_ERROR_NONE = P2WP_TELETEKST_ERROR_NONE,
    TELETEKST_ERROR_NOT_CONNECTED = P2WP_TELETEKST_ERROR_NOT_CONNECTED,
    TELETEKST_ERROR_TLS_CONFIG = P2WP_TELETEKST_ERROR_TLS_CONFIG,
    TELETEKST_ERROR_REQUEST_START = P2WP_TELETEKST_ERROR_REQUEST_START,
    TELETEKST_ERROR_NETWORK = P2WP_TELETEKST_ERROR_NETWORK,
    TELETEKST_ERROR_HTTP_STATUS = P2WP_TELETEKST_ERROR_HTTP_STATUS,
    TELETEKST_ERROR_TOO_LARGE = P2WP_TELETEKST_ERROR_TOO_LARGE,
    TELETEKST_ERROR_INVALID_DATA = P2WP_TELETEKST_ERROR_INVALID_DATA,
    TELETEKST_ERROR_PAGE_NOT_FOUND = P2WP_TELETEKST_ERROR_PAGE_NOT_FOUND,
    TELETEKST_ERROR_DNS = P2WP_TELETEKST_ERROR_DNS,
    TELETEKST_ERROR_CONNECT = P2WP_TELETEKST_ERROR_CONNECT,
    TELETEKST_ERROR_CONNECTION_CLOSED =
        P2WP_TELETEKST_ERROR_CONNECTION_CLOSED,
    TELETEKST_ERROR_TIMEOUT = P2WP_TELETEKST_ERROR_TIMEOUT,
    TELETEKST_ERROR_OUT_OF_MEMORY = P2WP_TELETEKST_ERROR_OUT_OF_MEMORY,
    TELETEKST_ERROR_CONTENT_LENGTH = P2WP_TELETEKST_ERROR_CONTENT_LENGTH,
    TELETEKST_ERROR_LOCAL_ABORT = P2WP_TELETEKST_ERROR_LOCAL_ABORT,
};

enum version_check_error {
    VERSION_CHECK_ERROR_NONE = 0,
    VERSION_CHECK_ERROR_NOT_CONNECTED = 1,
    VERSION_CHECK_ERROR_TLS_CONFIG = 2,
    VERSION_CHECK_ERROR_REQUEST_START = 3,
    VERSION_CHECK_ERROR_NETWORK = 4,
    VERSION_CHECK_ERROR_HTTP_STATUS = 5,
    VERSION_CHECK_ERROR_INVALID_DATA = 6,
};

enum wifi_profile_state {
    WIFI_PROFILE_STATE_ABSENT = 0,
    WIFI_PROFILE_STATE_READY = 1,
    WIFI_PROFILE_STATE_BUSY = 2,
};

enum wifi_profile_operation {
    WIFI_PROFILE_OPERATION_NONE = 0,
    WIFI_PROFILE_OPERATION_CONNECT = 1,
    WIFI_PROFILE_OPERATION_SAVE = 2,
    WIFI_PROFILE_OPERATION_DELETE = 3,
};

enum custom_url_operation {
    CUSTOM_URL_OPERATION_NONE = 0,
    CUSTOM_URL_OPERATION_SAVE = 1,
    CUSTOM_URL_OPERATION_SETTINGS_SAVE = 2,
};

typedef struct {
    uint8_t ssid_length;
    uint8_t ssid[32];
    int16_t rssi;
    uint8_t security;
    uint32_t auth;
} wifi_result_t;

static p2wp_parser_t parser;
static p2wp_frame_t request;
static uint8_t encoded_response[P2WP_MAX_ENCODED];
static p2wp_firmware_core_t firmware_core;
static mutex_t wifi_mutex;
static uint8_t wifi_init_state;
static uint8_t wifi_scan_state;
static uint8_t wifi_connection_state;
static bool wifi_scan_requested;
static bool wifi_connect_requested;
static wifi_result_t wifi_results[WIFI_MAX_RESULTS];
static uint8_t wifi_result_count;
static absolute_time_t wifi_init_deadline;
static absolute_time_t wifi_scan_deadline;
static absolute_time_t wifi_connect_deadline;
static absolute_time_t wifi_failure_deadline;
static char wifi_ssid[33];
static char wifi_password[WIFI_MAX_PASSWORD + 1u];
static uint32_t wifi_connect_auth;
static uint8_t stored_profile_state;
static uint8_t stored_profile_error;
static uint8_t stored_profile_operation;
static uint8_t stored_profile_ssid[WIFI_PROFILE_MAX_SSID];
static uint8_t stored_profile_ssid_length;
static uint8_t stored_profile_password[WIFI_PROFILE_MAX_PASSWORD];
static uint8_t stored_profile_password_length;
static uint32_t stored_profile_auth;
static uint8_t stored_custom_url_operation;
static uint8_t stored_custom_url_length;
static char stored_custom_url[CUSTOM_ENDPOINT_URL_MAX];
static uint8_t stored_auto_start_source;
static bool wifi_scan_active;
static bool wifi_connection_active;
static int wifi_pending_failure_status;
static uint8_t teletekst_fetch_state;
static uint8_t teletekst_error;
static uint8_t teletekst_http_result;
static int8_t teletekst_lwip_error;
static uint16_t teletekst_http_status;
static bool teletekst_fetch_requested;
static bool teletekst_http_overflow;
static bool teletekst_tls_cleanup_pending;
static bool teletekst_http_active;
static bool teletekst_forced_timeout;
static absolute_time_t teletekst_fetch_deadline;
static struct altcp_pcb *teletekst_http_connection;
static size_t teletekst_http_length;
static char teletekst_http_body[TELETEKST_HTTP_BODY_MAX + 1u];
static uint8_t teletekst_screen[TELETEKST_SCREEN_SIZE];
static uint16_t teletekst_requested_page;
static uint8_t teletekst_requested_subpage;
static uint8_t teletekst_requested_source;
static uint8_t teletekst_next_subpage;
static uint16_t teletekst_previous_page;
static uint16_t teletekst_next_page;
static char teletekst_custom_url[CUSTOM_ENDPOINT_URL_MAX + 1u];
static uint8_t teletekst_custom_url_length;
static char teletekst_host[CUSTOM_ENDPOINT_HOST_MAX + 1u];
static char teletekst_path[CUSTOM_ENDPOINT_REQUEST_PATH_MAX];
static struct altcp_tls_config *teletekst_tls_config;
static const char *teletekst_tls_hostname;
static bool teletekst_tls_insecure;
static altcp_allocator_t teletekst_tls_allocator;
static httpc_connection_t teletekst_http_settings;
static struct udp_pcb *ntp_pcb;
static bool ntp_request_active;
static bool clock_valid;
static uint32_t clock_unix_seconds;
static absolute_time_t clock_reference;
static absolute_time_t ntp_next_attempt;
static absolute_time_t ntp_request_deadline;
static uint8_t version_check_state;
static uint8_t version_check_error;
static bool version_check_requested;
static bool version_http_overflow;
static bool version_tls_cleanup_pending;
static size_t version_http_length;
static char version_http_body[VERSION_HTTP_BODY_MAX + 1u];
static p2wp_release_version_t latest_release_version;
static struct altcp_tls_config *version_tls_config;
static altcp_allocator_t version_tls_allocator;
static httpc_connection_t version_http_settings;

#if defined(PICO_RP2350) && PICO_RP2350
static const uint8_t hardware_model = P2WP_HARDWARE_PICO_2_W;
#else
static const uint8_t hardware_model = P2WP_HARDWARE_PICO_W;
#endif

/** Return the synchronized Unix time, or zero until the first NTP reply. */
static uint32_t clock_now(void) {
    uint32_t seconds = 0u;
    mutex_enter_blocking(&wifi_mutex);
    if (clock_valid) {
        const int64_t elapsed = absolute_time_diff_us(
            clock_reference,
            get_absolute_time()
        );
        if (elapsed >= 0) {
            seconds = clock_unix_seconds + (uint32_t)(elapsed / 1000000);
        }
    }
    mutex_exit(&wifi_mutex);
    return seconds;
}

/** Convert a Unix timestamp to Dutch local date and time (CET/CEST). */
static bool clock_local_components(uint32_t unix_time, uint8_t result[7]) {
    if (unix_time == 0u) {
        memset(result, 0, 7u);
        return false;
    }
    const uint32_t days = unix_time / 86400u;
    uint32_t first_day = 0u;
    unsigned year = 1970u;
    while (true) {
        const bool leap = (year % 4u == 0u && year % 100u != 0u) ||
                          year % 400u == 0u;
        const uint32_t year_days = leap ? 366u : 365u;
        if (days < first_day + year_days) {
            break;
        }
        first_day += year_days;
        ++year;
    }
    const bool leap = (year % 4u == 0u && year % 100u != 0u) ||
                      year % 400u == 0u;
    // Sunday is zero; Unix day zero (1970-01-01) was Thursday.
    const uint32_t march_31 = first_day + 31u + 28u + (leap ? 1u : 0u) + 30u;
    const uint32_t october_31 = first_day + 304u;
    const uint32_t dst_start_day = march_31 - ((march_31 + 4u) % 7u);
    const uint32_t dst_end_day = october_31 - ((october_31 + 4u) % 7u);
    const uint32_t dst_start = dst_start_day * 86400u + 3600u;
    const uint32_t dst_end = dst_end_day * 86400u + 3600u;
    const uint32_t offset = 3600u +
        (unix_time >= dst_start && unix_time < dst_end ? 3600u : 0u);
    const uint32_t local_time = unix_time + offset;
    const uint32_t local_days = local_time / 86400u;
    const uint32_t day_seconds = local_time % 86400u;
    first_day = 0u;
    year = 1970u;
    while (true) {
        const bool local_leap =
            (year % 4u == 0u && year % 100u != 0u) || year % 400u == 0u;
        const uint32_t year_days = local_leap ? 366u : 365u;
        if (local_days < first_day + year_days) {
            break;
        }
        first_day += year_days;
        ++year;
    }
    const bool local_leap =
        (year % 4u == 0u && year % 100u != 0u) || year % 400u == 0u;
    static const uint8_t month_days[12] = {
        31u, 28u, 31u, 30u, 31u, 30u, 31u, 31u, 30u, 31u, 30u, 31u
    };
    uint32_t day_of_year = local_days - first_day;
    unsigned month = 0u;
    while (month < 11u) {
        uint32_t days_in_month = month_days[month];
        if (month == 1u && local_leap) {
            ++days_in_month;
        }
        if (day_of_year < days_in_month) {
            break;
        }
        day_of_year -= days_in_month;
        ++month;
    }
    result[0] = (uint8_t)(day_seconds / 3600u);
    result[1] = (uint8_t)((day_seconds / 60u) % 60u);
    result[2] = (uint8_t)(day_seconds % 60u);
    result[3] = (uint8_t)(day_of_year + 1u);
    result[4] = (uint8_t)(month + 1u);
    result[5] = (uint8_t)(year - 2000u);
    // Sunday is zero; Unix day zero (1970-01-01) was Thursday.
    result[6] = (uint8_t)((local_days + 4u) % 7u);
    return true;
}

/** Send one minimal NTP client request to a resolved server address. */
static void ntp_send_request(const ip_addr_t *address) {
    if (ntp_pcb == NULL) {
        return;
    }
    struct pbuf *packet = pbuf_alloc(PBUF_TRANSPORT, NTP_PACKET_SIZE, PBUF_RAM);
    if (packet == NULL) {
        ntp_next_attempt = make_timeout_time_ms(NTP_RETRY_MS);
        return;
    }
    memset(packet->payload, 0, NTP_PACKET_SIZE);
    ((uint8_t *)packet->payload)[0] = 0x23u; // NTP v4 client request.
    if (udp_sendto(ntp_pcb, packet, address, NTP_PORT) == ERR_OK) {
        ntp_request_active = true;
        ntp_request_deadline = make_timeout_time_ms(NTP_RETRY_MS);
    } else {
        ntp_next_attempt = make_timeout_time_ms(NTP_RETRY_MS);
    }
    pbuf_free(packet);
}

/** Continue an NTP request after asynchronous DNS resolution. */
static void ntp_dns_found(const char *name, const ip_addr_t *address, void *arg) {
    (void)name;
    (void)arg;
    if (address == NULL) {
        ntp_request_active = false;
        ntp_next_attempt = make_timeout_time_ms(NTP_RETRY_MS);
        return;
    }
    ntp_send_request(address);
}

/** Accept an NTP transmit timestamp and establish the Pico's wall clock. */
static void ntp_receive(
    void *arg,
    struct udp_pcb *pcb,
    struct pbuf *packet,
    const ip_addr_t *address,
    u16_t port
) {
    (void)arg;
    (void)pcb;
    (void)address;
    (void)port;
    uint8_t timestamp[4];
    if (packet->tot_len >= NTP_PACKET_SIZE &&
        pbuf_copy_partial(packet, timestamp, sizeof(timestamp), 40u) ==
            sizeof(timestamp)) {
        const uint32_t ntp_seconds =
            ((uint32_t)timestamp[0] << 24u) |
            ((uint32_t)timestamp[1] << 16u) |
            ((uint32_t)timestamp[2] << 8u) |
            (uint32_t)timestamp[3];
        if (ntp_seconds >= NTP_UNIX_EPOCH_OFFSET) {
            mutex_enter_blocking(&wifi_mutex);
            clock_unix_seconds = ntp_seconds - NTP_UNIX_EPOCH_OFFSET;
            clock_reference = get_absolute_time();
            clock_valid = true;
            mutex_exit(&wifi_mutex);
            ntp_next_attempt = make_timeout_time_ms(NTP_RESYNC_MS);
        }
    }
    ntp_request_active = false;
    pbuf_free(packet);
}

/** Start or periodically resynchronize the wall clock while Wi-Fi is up. */
static void ntp_service(bool connected) {
    if (!connected) {
        return;
    }
    if (ntp_request_active && time_reached(ntp_request_deadline)) {
        ntp_request_active = false;
        ntp_next_attempt = make_timeout_time_ms(NTP_RETRY_MS);
    }
    if (ntp_request_active || !time_reached(ntp_next_attempt)) {
        return;
    }
    if (ntp_pcb == NULL) {
        ntp_pcb = udp_new_ip_type(IPADDR_TYPE_ANY);
        if (ntp_pcb == NULL) {
            ntp_next_attempt = make_timeout_time_ms(NTP_RETRY_MS);
            return;
        }
        udp_recv(ntp_pcb, ntp_receive, NULL);
    }
    ip_addr_t address;
    const err_t result = dns_gethostbyname(NTP_HOST, &address, ntp_dns_found, NULL);
    if (result == ERR_OK) {
        ntp_send_request(&address);
    } else if (result != ERR_INPROGRESS) {
        ntp_next_attempt = make_timeout_time_ms(NTP_RETRY_MS);
    } else {
        ntp_request_active = true;
        ntp_request_deadline = make_timeout_time_ms(NTP_RETRY_MS);
    }
}

/**
 * @brief Publish a terminal Teletekst fetch error to the mailbox core.
 *
 * @param error TELETEKST_ERROR_* value describing the failure.
 */
static void teletekst_set_failed(uint8_t error) {
    mutex_enter_blocking(&wifi_mutex);
    teletekst_fetch_state = TELETEKST_FETCH_FAILED;
    teletekst_error = error;
    mutex_exit(&wifi_mutex);
}

/** Convert lwIP HTTP completion states into stable P2WP/7 error codes. */
static uint8_t teletekst_http_error(httpc_result_t result) {
    switch (result) {
        case HTTPC_RESULT_ERR_HOSTNAME:
            return TELETEKST_ERROR_DNS;
        case HTTPC_RESULT_ERR_CONNECT:
            return TELETEKST_ERROR_CONNECT;
        case HTTPC_RESULT_ERR_CLOSED:
            return TELETEKST_ERROR_CONNECTION_CLOSED;
        case HTTPC_RESULT_ERR_TIMEOUT:
            return TELETEKST_ERROR_TIMEOUT;
        case HTTPC_RESULT_ERR_MEM:
            return TELETEKST_ERROR_OUT_OF_MEMORY;
        case HTTPC_RESULT_ERR_CONTENT_LEN:
            return TELETEKST_ERROR_CONTENT_LENGTH;
        case HTTPC_RESULT_LOCAL_ABORT:
            return TELETEKST_ERROR_LOCAL_ABORT;
        case HTTPC_RESULT_ERR_SVR_RESP:
            return TELETEKST_ERROR_HTTP_STATUS;
        case HTTPC_RESULT_ERR_UNKNOWN:
        case HTTPC_RESULT_OK:
        default:
            return TELETEKST_ERROR_NETWORK;
    }
}

/** Classify failures returned before lwIP can start an HTTP transaction. */
static uint8_t teletekst_request_start_error(err_t error) {
    switch (error) {
        case ERR_MEM:
        case ERR_BUF:
            return TELETEKST_ERROR_OUT_OF_MEMORY;
        case ERR_TIMEOUT:
            return TELETEKST_ERROR_TIMEOUT;
        case ERR_ABRT:
            return TELETEKST_ERROR_LOCAL_ABORT;
        case ERR_RST:
        case ERR_CLSD:
            return TELETEKST_ERROR_CONNECTION_CLOSED;
        case ERR_RTE:
        case ERR_CONN:
        case ERR_IF:
            return TELETEKST_ERROR_CONNECT;
        default:
            return TELETEKST_ERROR_REQUEST_START;
    }
}

/**
 * @brief Allocate an lwIP TLS connection and configure hostname validation.
 *
 * @param arg TLS configuration supplied through the lwIP allocator interface.
 * @param ip_type lwIP address-family selector.
 * @return Configured connection, or NULL when allocation/setup fails.
 */
static struct altcp_pcb *teletekst_tls_alloc(void *arg, u8_t ip_type) {
    struct altcp_pcb *connection = altcp_tls_alloc(arg, ip_type);
    if (connection == NULL) {
        return NULL;
    }
    mbedtls_ssl_context *context = altcp_tls_context(connection);
    if (context == NULL || teletekst_tls_hostname == NULL ||
        mbedtls_ssl_set_hostname(context, teletekst_tls_hostname) != 0) {
        altcp_abort(connection);
        return NULL;
    }
    if (teletekst_tls_insecure) {
        mbedtls_ssl_set_hs_authmode(context, MBEDTLS_SSL_VERIFY_NONE);
    }
    teletekst_http_connection = connection;
    return connection;
}

/** Allocate and retain a plain TCP connection so timed-out HTTP can abort. */
static struct altcp_pcb *teletekst_tcp_alloc(void *arg, u8_t ip_type) {
    (void)arg;
    teletekst_http_connection = altcp_tcp_new_ip_type(ip_type);
    return teletekst_http_connection;
}

/**
 * @brief Record HTTP response metadata after lwIP has parsed the headers.
 *
 * @param connection Active HTTP client state.
 * @param argument Caller context; unused.
 * @param headers Header pbuf chain; unused after lwIP validation.
 * @param header_length Encoded header length; unused.
 * @param content_length Declared body length, or UINT32_MAX when unknown.
 * @return ERR_OK so lwIP continues delivering the response body.
 */
static err_t teletekst_headers_done(
    httpc_state_t *connection,
    void *argument,
    struct pbuf *headers,
    u16_t header_length,
    u32_t content_length
) {
    (void)connection;
    (void)argument;
    (void)headers;
    (void)header_length;

    mutex_enter_blocking(&wifi_mutex);
    teletekst_fetch_state = TELETEKST_FETCH_RECEIVING;
    if (content_length != UINT32_MAX &&
        content_length > TELETEKST_HTTP_BODY_MAX) {
        teletekst_http_overflow = true;
    }
    mutex_exit(&wifi_mutex);
    return ERR_OK;
}

/**
 * @brief Append one received pbuf chain to the bounded Teletekst body buffer.
 *
 * The callback always acknowledges and frees the pbuf. Overflow is remembered
 * so the completion callback can return error 06 without writing out of bounds.
 *
 * @param argument Caller context; unused.
 * @param connection Active TLS connection used for receive-window accounting.
 * @param data Received pbuf chain, or NULL when no data is supplied.
 * @param error lwIP receive status; completion handles the final result.
 * @return ERR_OK after consuming the supplied data.
 */
static err_t teletekst_receive(
    void *argument,
    struct altcp_pcb *connection,
    struct pbuf *data,
    err_t error
) {
    (void)argument;
    (void)error;
    if (data == NULL) {
        return ERR_OK;
    }

    mutex_enter_blocking(&wifi_mutex);
    if (data->tot_len > TELETEKST_HTTP_BODY_MAX - teletekst_http_length) {
        teletekst_http_overflow = true;
    } else {
        for (struct pbuf *part = data; part != NULL; part = part->next) {
            memcpy(
                teletekst_http_body + teletekst_http_length,
                part->payload,
                part->len
            );
            teletekst_http_length += part->len;
        }
    }
    teletekst_fetch_state = TELETEKST_FETCH_RECEIVING;
    mutex_exit(&wifi_mutex);

    altcp_recved(connection, data->tot_len);
    pbuf_free(data);
    return ERR_OK;
}
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
int main(void) {
    mailbox_init();
    mutex_init(&wifi_mutex);
    p2wp_firmware_core_init(
        &firmware_core,
        &pico_firmware_operations,
        NULL,
        hardware_model
    );
    version_check_state = P2WP_VERSION_CHECK_IDLE;
    version_check_error = VERSION_CHECK_ERROR_NONE;
    wifi_init_state = WIFI_INIT_STARTING;
    stored_profile_state = wifi_profile_present()
        ? WIFI_PROFILE_STATE_READY
        : WIFI_PROFILE_STATE_ABSENT;
    stored_profile_error = WIFI_PROFILE_OK;
    wifi_init_deadline = make_timeout_time_ms(WIFI_INIT_TIMEOUT_MS);
    p2wp_parser_init(&parser);

    // Start the local link before the blocking radio bring-up. This keeps
    // HELLO and status polling responsive even if CYW43 hardware is absent.
    multicore_launch_core1(mailbox_core_main);
    wifi_radio_main();
}

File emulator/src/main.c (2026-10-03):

#include "P2000.h"
#include "p2wp_device.h"
#include "page_backend.h"

#include <SDL.h>
#include <errno.h>
#include <stdint.h>
#include <stdio.h>
#include <stdlib.h>
#include <string.h>

enum { WIDTH = 40 * 6 * 3, HEIGHT = 24 * 10 * 3, FONT_BYTES = 2240 };
static SDL_Window *window;
static SDL_Renderer *renderer;
static SDL_Texture *texture;
static uint32_t pixels[HEIGHT][WIDTH];
static uint8_t font_data[FONT_BYTES];
static const uint32_t palette[8] = {0xff000000, 0xffff0000, 0xff00ff00,
                                    0xffffff00, 0xff0000ff, 0xffff00ff,
                                    0xff00ffff, 0xffffffff};
static int running = 1, headless = 0, auto_keys = 0, auto_source = 1;
static int auto_source_cycles;
static int auto_channel, auto_channel_page;
static const char *auto_custom_server;
static const char *auto_action;
static int auto_wait_opening;
static int auto_pause_frame = -1, auto_resume_frame = -1;
static int protocol_version = 0;
static int status_length = 0;
static int wifi_profile = 0;
static int wifi_security = 0;
static int wifi_password_visible = 0;
static const char *dump_path, *dump_frame_path, *dump_fetches_path,
    *dump_pages_path, *dump_sources_path;
static const char *flash_path;
static int fail_page, fail_error;
static int fixture_repeats_next_subpage;
static int fetch_stall_after = -1;
static int firmware_fetch_timeout = 1;
static int clock_valid = 1;
static uint8_t queued_keys[16];
static size_t queued_head, queued_tail;

static void queue_monitor_key(int code) {
  if (queued_tail - queued_head < sizeof(queued_keys))
    queued_keys[queued_tail++ % sizeof(queued_keys)] = (uint8_t)code;
}

void PicoCard_Out(byte port, byte value) { p2wp_device_out(port, value); }
byte PicoCard_In(byte port) { return p2wp_device_in(port); }
void EmulatorControl_Out(byte port, byte value) {
  (void)value;
  if (port == 0xfc)
    queued_head = queued_tail = 0;
}
byte EmulatorControl_In(byte port) {
  if (port == 0xfd)
    return queued_head != queued_tail
               ? (queued_keys[queued_head % sizeof(queued_keys)] == 0x58 ? 3
                                                                         : 1)
               : 0;
  if (port == 0xfe && queued_head != queued_tail)
    return queued_keys[queued_head++ % sizeof(queued_keys)];
  return 0;
}
int InitMachine(void) { return 1; }
void TrashMachine(void) {}
void Sound(int v) { (void)v; }
void FlushSound(void) {}
void SyncEmulation(void) {}
void Pause(int ms) { SDL_Delay((unsigned)ms); }
char *GetResourcesPath(void) { return "."; }
char *GetDocumentsPath(void) { return "."; }
void ShowErrorMessage(const char *f, ...) { fprintf(stderr, "%s\n", f); }
int LoadFont(const char *name) {
  FILE *f = fopen(name, "rb");
  if (!f)
    return 0;
  int ok = fread(font_data, 1, sizeof(font_data), f) == sizeof(font_data);
  fclose(f);
  return ok;
}
void PutChar(int x, int y, int c, int fg, int bg, int dh) {
  if (x < 0 || x >= 40 || y < 0 || y >= 24 || c < 0 || c >= 224)
    return;
  for (int oy = 0; oy < 10; oy++) {
    int sy = dh == 1 ? oy / 2 : dh == 2 ? 5 + oy / 2 : oy;
    uint8_t bits = font_data[c * 10 + sy];
    for (int ox = 0; ox < 6; ox++) {
      uint32_t color = palette[(bits & (0x20 >> ox)) ? (fg & 7) : (bg & 7)];
      for (int yy = 0; yy < 3; yy++)
        for (int xx = 0; xx < 3; xx++)
          pixels[y * 30 + oy * 3 + yy][x * 18 + ox * 3 + xx] = color;
    }
  }
}
void PutImage(void) {
  if (headless)
    return;
  SDL_UpdateTexture(texture, NULL, pixels, WIDTH * 4);
  SDL_RenderClear(renderer);
  SDL_RenderCopy(renderer, texture, NULL, NULL);
  SDL_RenderPresent(renderer);
}

static int keycode(SDL_Keycode key) {
  if (key >= 'a' && key <= 'z') {
    static const uint8_t map[26] = {34, 29, 28, 12, 36, 15, 13, 9, 70,
                                    14, 62, 65, 30, 25, 49, 53, 3, 39,
                                    11, 37, 38, 31, 35, 27, 33, 10};
    return map[key - 'a'];
  }
  if (key >= '0' && key <= '9') {
    static const uint8_t map[10] = {45, 46, 63, 4, 7, 5, 1, 6, 54, 41};
    return map[key - '0'];
  }
  switch (key) {
  case SDLK_SPACE:
    return 17;
  case SDLK_RETURN:
    return 52;
  case SDLK_BACKSPACE:
    return 44;
  case SDLK_SLASH:
    return 61;
  case SDLK_PERIOD:
    return 57;
  case SDLK_MINUS:
    return 47;
  case SDLK_SEMICOLON:
  case SDLK_COLON:
    return 71;
  case SDLK_LEFT:
    return 0;
  case SDLK_UP:
    return 2;
  case SDLK_DOWN:
    return 21;
  case SDLK_RIGHT:
    return 23;
  case SDLK_LSHIFT:
    return 72;
  case SDLK_RSHIFT:
    return 79;
  case SDLK_KP_ENTER:
    return 16;
  case SDLK_KP_0:
    return 19;
  case SDLK_KP_1:
    return 59;
  case SDLK_KP_2:
    return 58;
  case SDLK_KP_3:
    return 56;
  case SDLK_KP_4:
    return 67;
  case SDLK_KP_5:
    return 66;
  case SDLK_KP_6:
    return 64;
  case SDLK_KP_7:
    return 51;
  case SDLK_KP_8:
    return 50;
  case SDLK_KP_9:
    return 48;
  default:
    return -1;
  }
}
void Keyboard(void) {
  if (headless)
    return;
  SDL_Event e;
  while (SDL_PollEvent(&e)) {
    if (e.type == SDL_QUIT)
      running = 0;
    if (e.type == SDL_KEYDOWN && !e.key.repeat &&
        e.key.keysym.sym == SDLK_F11) {
      WarmReset();
      continue;
    }
    if (e.type == SDL_KEYDOWN && !e.key.repeat &&
        e.key.keysym.sym == SDLK_F12) {
      ColdReset();
      continue;
    }
    if (e.type == SDL_KEYDOWN || e.type == SDL_KEYUP) {
      int code = keycode(e.key.keysym.sym);
      if (code >= 0) {
        int row = code / 8, bit = code % 8;
        if (e.type == SDL_KEYDOWN) {
          KeyMap[row] &= (byte) ~(1u << bit);
          if (!e.key.repeat)
            queue_monitor_key(code);
        } else
          KeyMap[row] |= (byte)(1u << bit);
      }
    }
  }
}

static void set_matrix_key(int code, int down) {
  int row = code / 8, bit = code % 8;
  if (down)
    KeyMap[row] &= (byte) ~(1u << bit);
  else
    KeyMap[row] |= (byte)(1u << bit);
}
static int screen_has(const char *text) {
  size_t n = strlen(text);
  for (int row = 0; row < 24; row++)
    for (int col = 0; col + (int)n <= 40; col++)
      if (!memcmp(VRAM + row * 80 + col, text, n))
        return 1;
  return 0;
}
static void inject_key(int code) {
  if (code < 80)
    set_matrix_key(code, 1);
  queue_monitor_key(code);
}
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

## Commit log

2026-08-17 Adding LICENSE and links
    [teletekst-bottom.stl]
2026-08-21 Removing diode from design, hardening interface
    [p2000t-pico-web-interface.kicad_pcb, p2000t-pico-web-interface.kicad_sch]
2026-08-24 Patching bug in NOS TT HTML parser
    [main.c]
2026-08-24 Expanding comments and adding enclosure image
2026-08-28 Changing language to Dutch and adding new shortkeys (#1)
    [p2000t-pico-web-interface-B_Cu.gbr, p2000t-pico-web-interface-B_Mask.gbr, p2000t-pico-web-interface-B_Paste.gbr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]
2026-09-08 Patch v0.5.0 (#4)
    * Detecting latest version
    * Integrating unit tests and improving firmware testing and emulation
    * Creating custom server option with example Python-based server
    * Storing last used URL
    * Implementing issue #2 and adding new teletekst URL
    * Adding auto-login timer
    * Tackling issue #2
    * Fixing non-advancing clock
2026-10-01 v0.5.0: C cartridge, custom sources, and firmware/UI improvements (#7)
    * Cartridgefirmware porteren naar onderhoudbare Z88DK C-code (#5)
    * Interim commit porting to C
    * Further converting to C code
    * Implementing Doxygen style coding and further compressing ROM
    * Fix C viewer rotation and CI documentation
    * Redesign source selection and help screens
    * Adding emulator to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
    [main.c]
2026-10-09 Adding LEDs to PCB
